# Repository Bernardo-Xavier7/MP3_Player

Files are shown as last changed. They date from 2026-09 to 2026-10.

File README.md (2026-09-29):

# Description
Just a simple MP3 player project. Features a built-in microphone, FM module, Wifi and Bluetooth, internal flash and SD card support and two audio ports.

# To-Do
- [ ] Hardware
  - [x] Schematic
    - [x] MCU
    - [x] USB
    - [x] Power
    - [x] Audio
    - [x] Storage
    - [x] Buttons
    - [x] Display
    - [x] Wireless
    - [x] Revision
    - [x] BOM
    - [x] Footprint Assignment
  - [ ] PCB
    - [ ] Layout
    - [ ] Routing
    - [ ] Revision
  - [ ] Firmware
    - [ ] Menu
      - [ ] Buttons
      - [ ] Display
    - [ ] USB Handling
    - [ ] Power Measuring and Display
    - [ ] Play Audio
    - [ ] Record
    - [ ] SD Card File System and Mass Storage
    - [ ] Wireless Conectivity
    - [ ] Revision
  - [ ] Case
    - [ ] Model
    - [ ] Test
    - [ ] Revision
# Useful Links
| Link | Description |
| ---- | ---- |
| https://snapeda.com | Symbols/Footprints/3DModels |
| https://octopart.com | Multi-seller component browser |
| https://buydisplay.com | Display shop |
| https://panelook.com | Display shop |
| [https://dev.st.com](https://dev.st.com/stm32cube-docs/stm32cube-getting-started/1.1.1/en/markup/Ecosystem_Select/Ecosystem_Select_MCU_Board.html) | STM32 development guide |

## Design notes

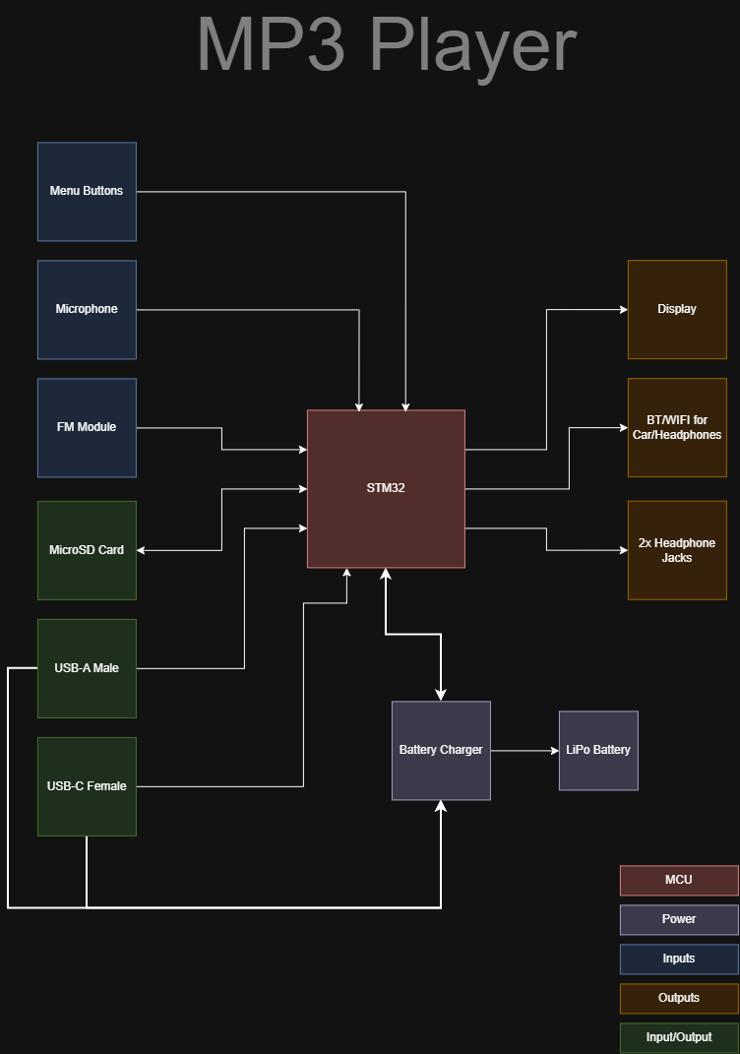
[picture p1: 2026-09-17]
PCB/MP3_Player/Drawings/MP3 Player.drawio.png

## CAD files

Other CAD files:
Case/MP3_Player.FCStd

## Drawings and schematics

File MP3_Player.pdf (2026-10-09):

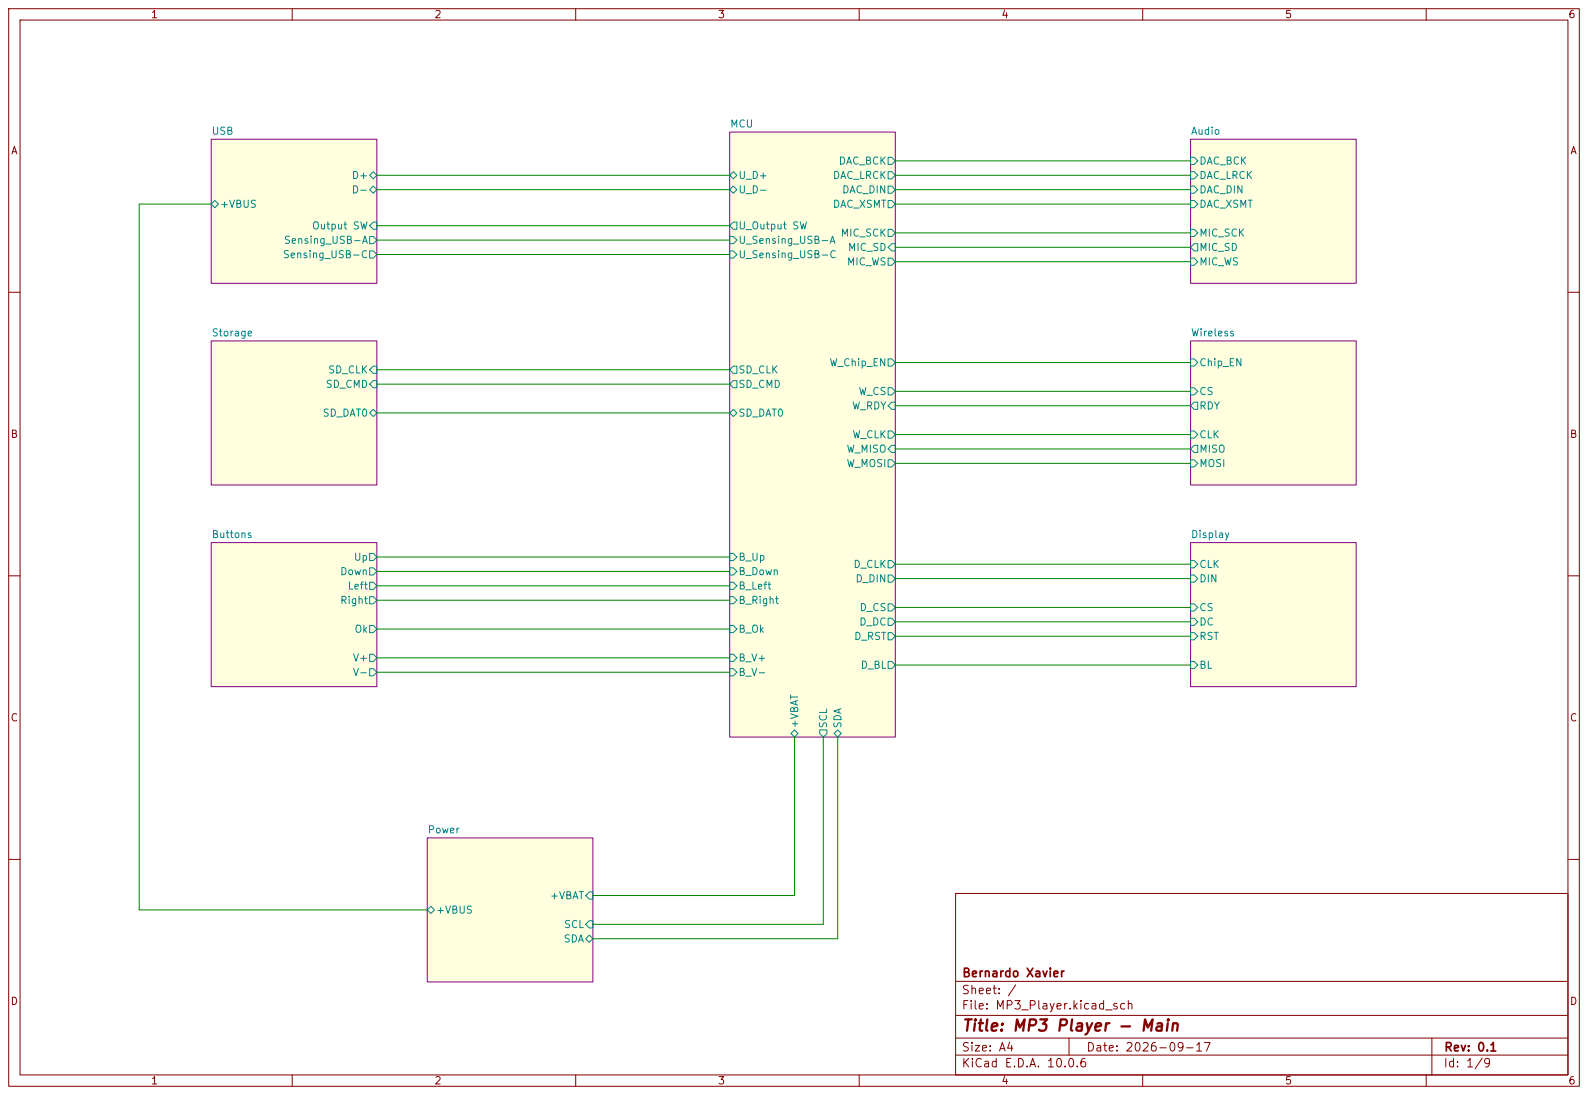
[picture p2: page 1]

Size: A4 | Rev: 0.1
KiCad E.D.A. 10.0.6 | Id: 1/9

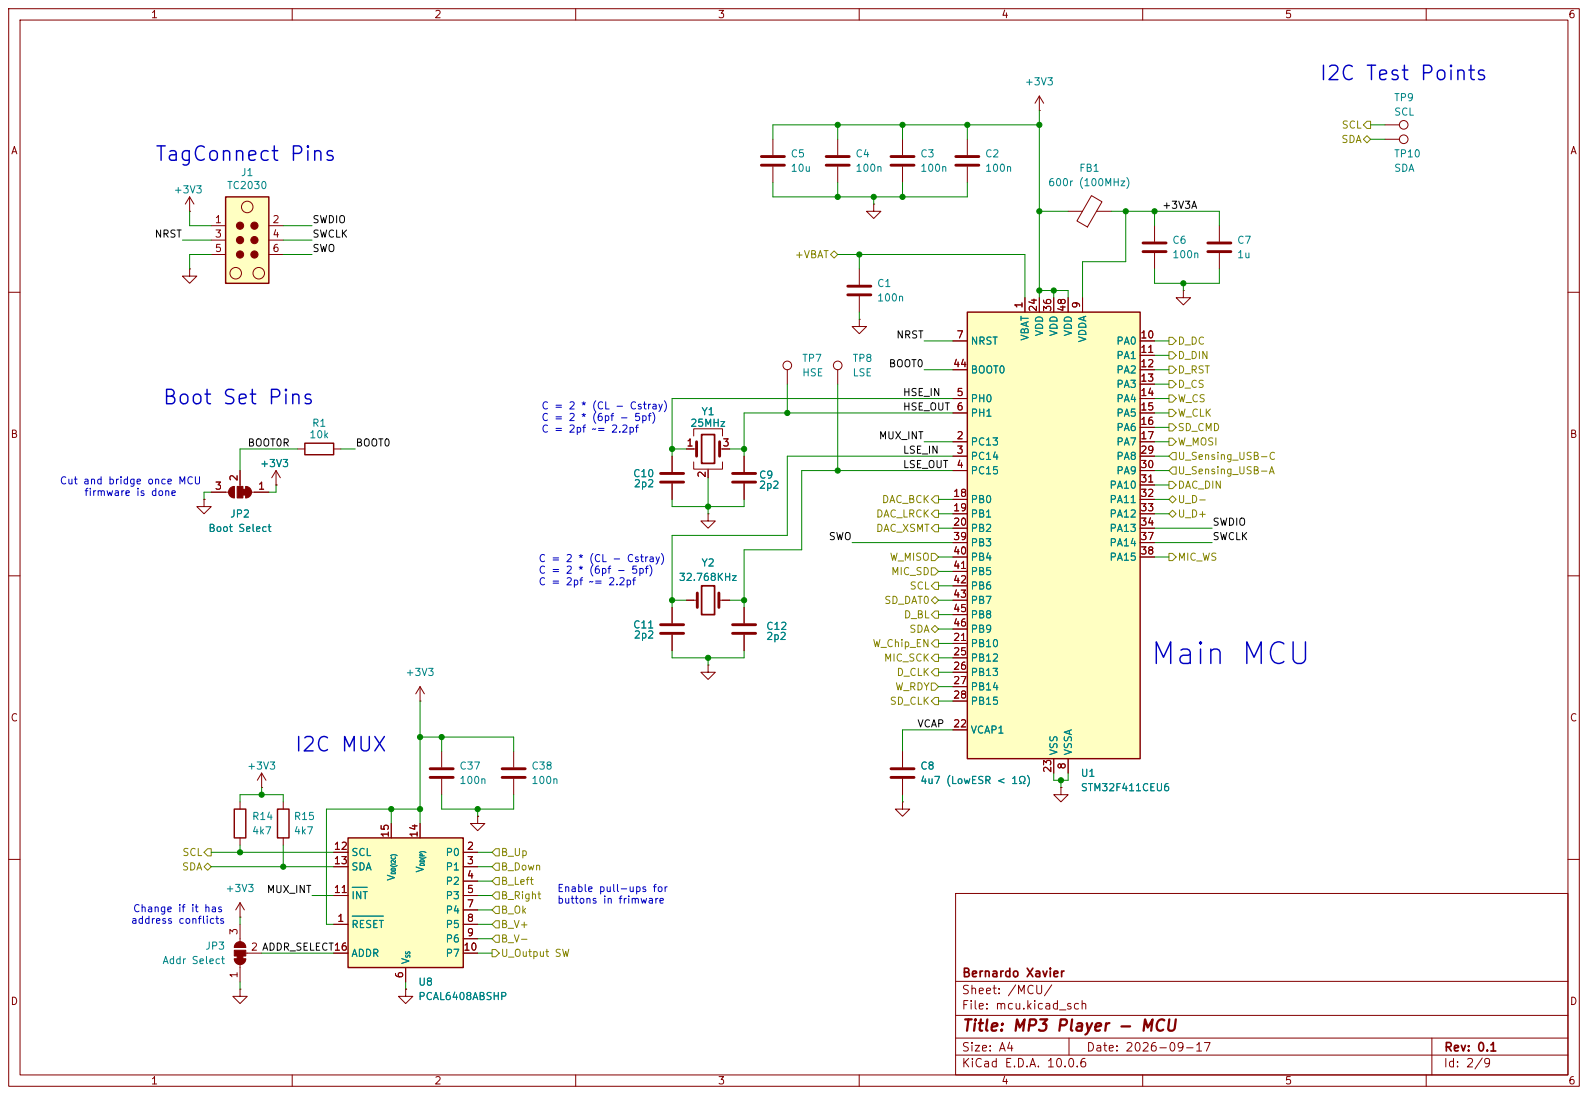
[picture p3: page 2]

C = 2 * (CL - Cstray) C = 2 * (6pf - 5pf) C = 2pf ~= 2.2pf C = 2 * (CL - Cstray) C = 2 * (6pf - 5pf) C = 2pf ~= 2.2pf Enable pull-ups for buttons in frimware TagConnect Pins

Cut and bridge once MCU

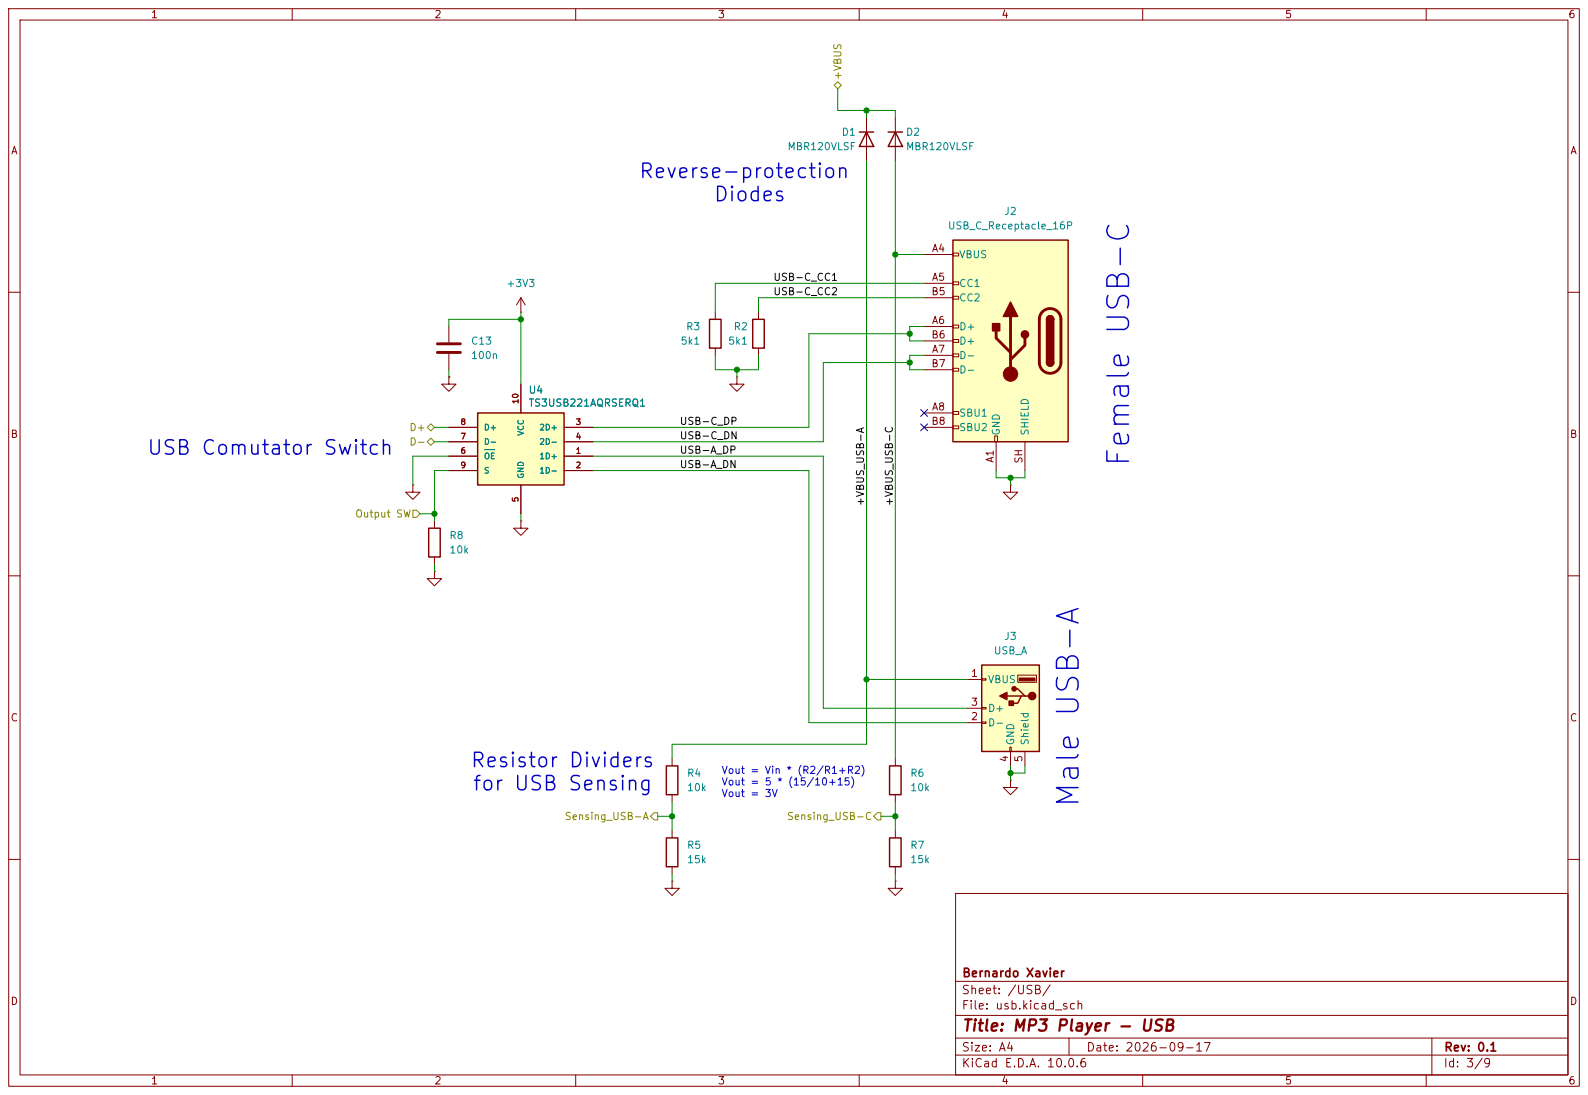
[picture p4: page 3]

SBU1 A8 CC2 B5 D+ B6 D- B7 SBU2 B8

SHIELD SH

Vout = Vin * (R2/R1+R2) Vout = 5 * (15/10+15) Vout = 3V USB Comutator Switch

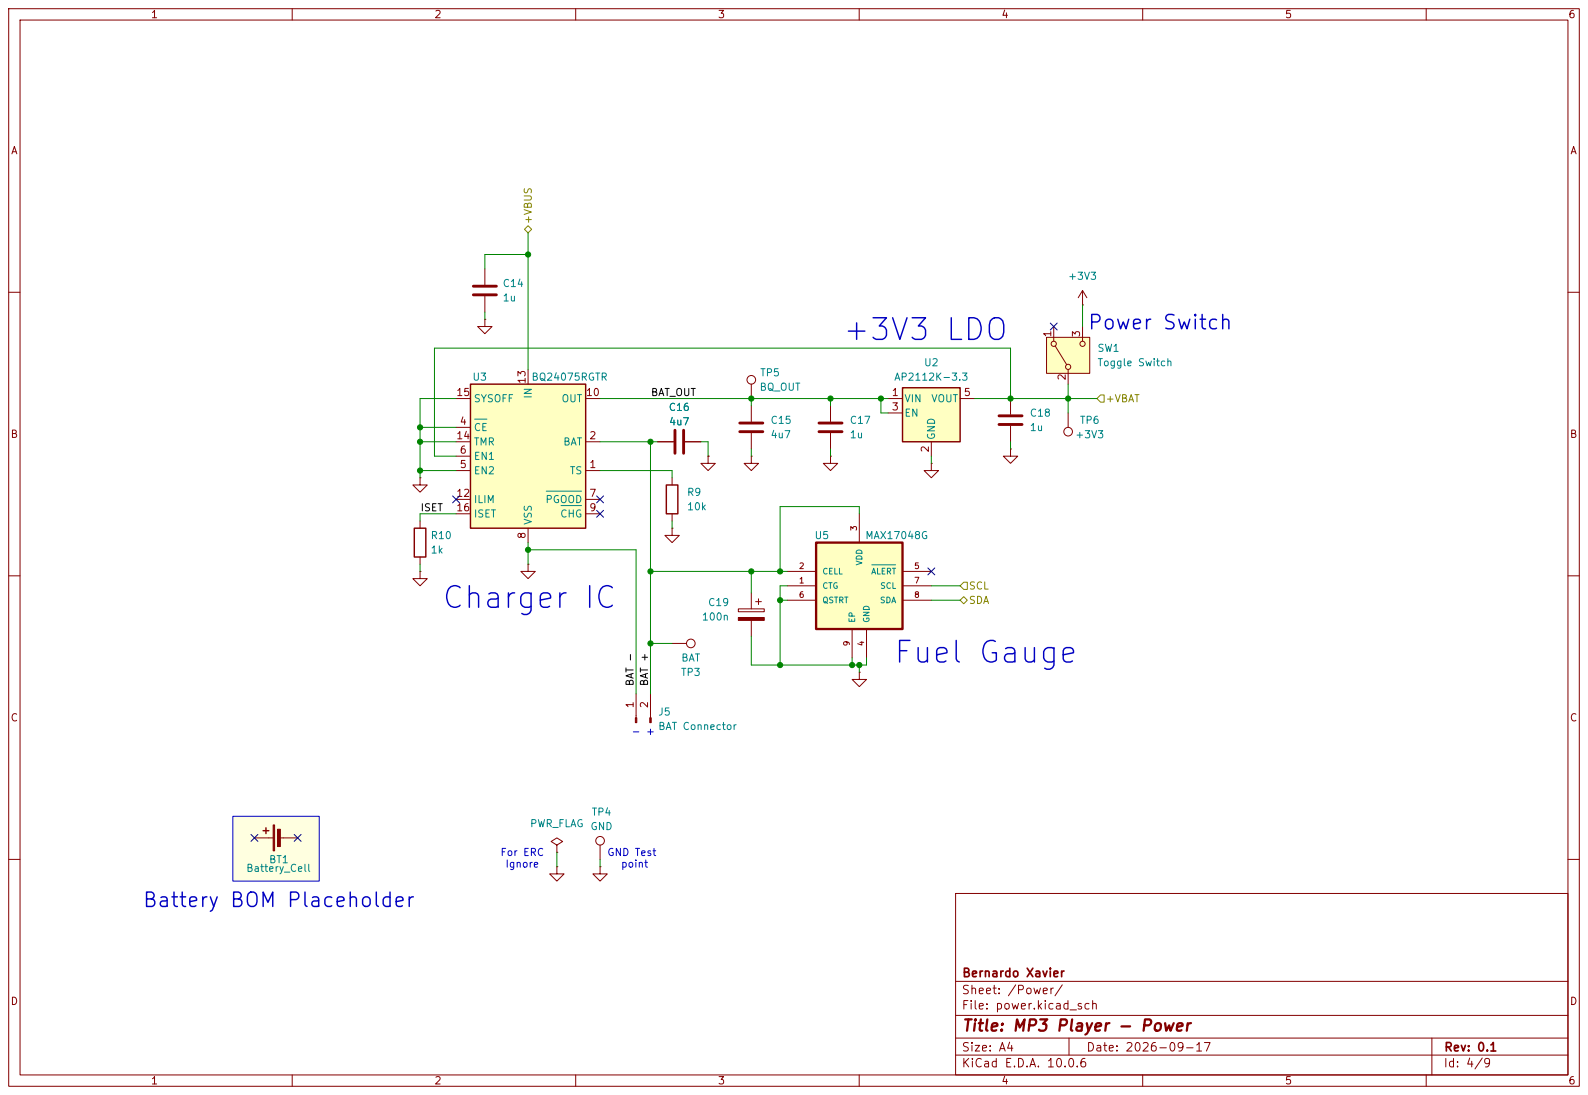
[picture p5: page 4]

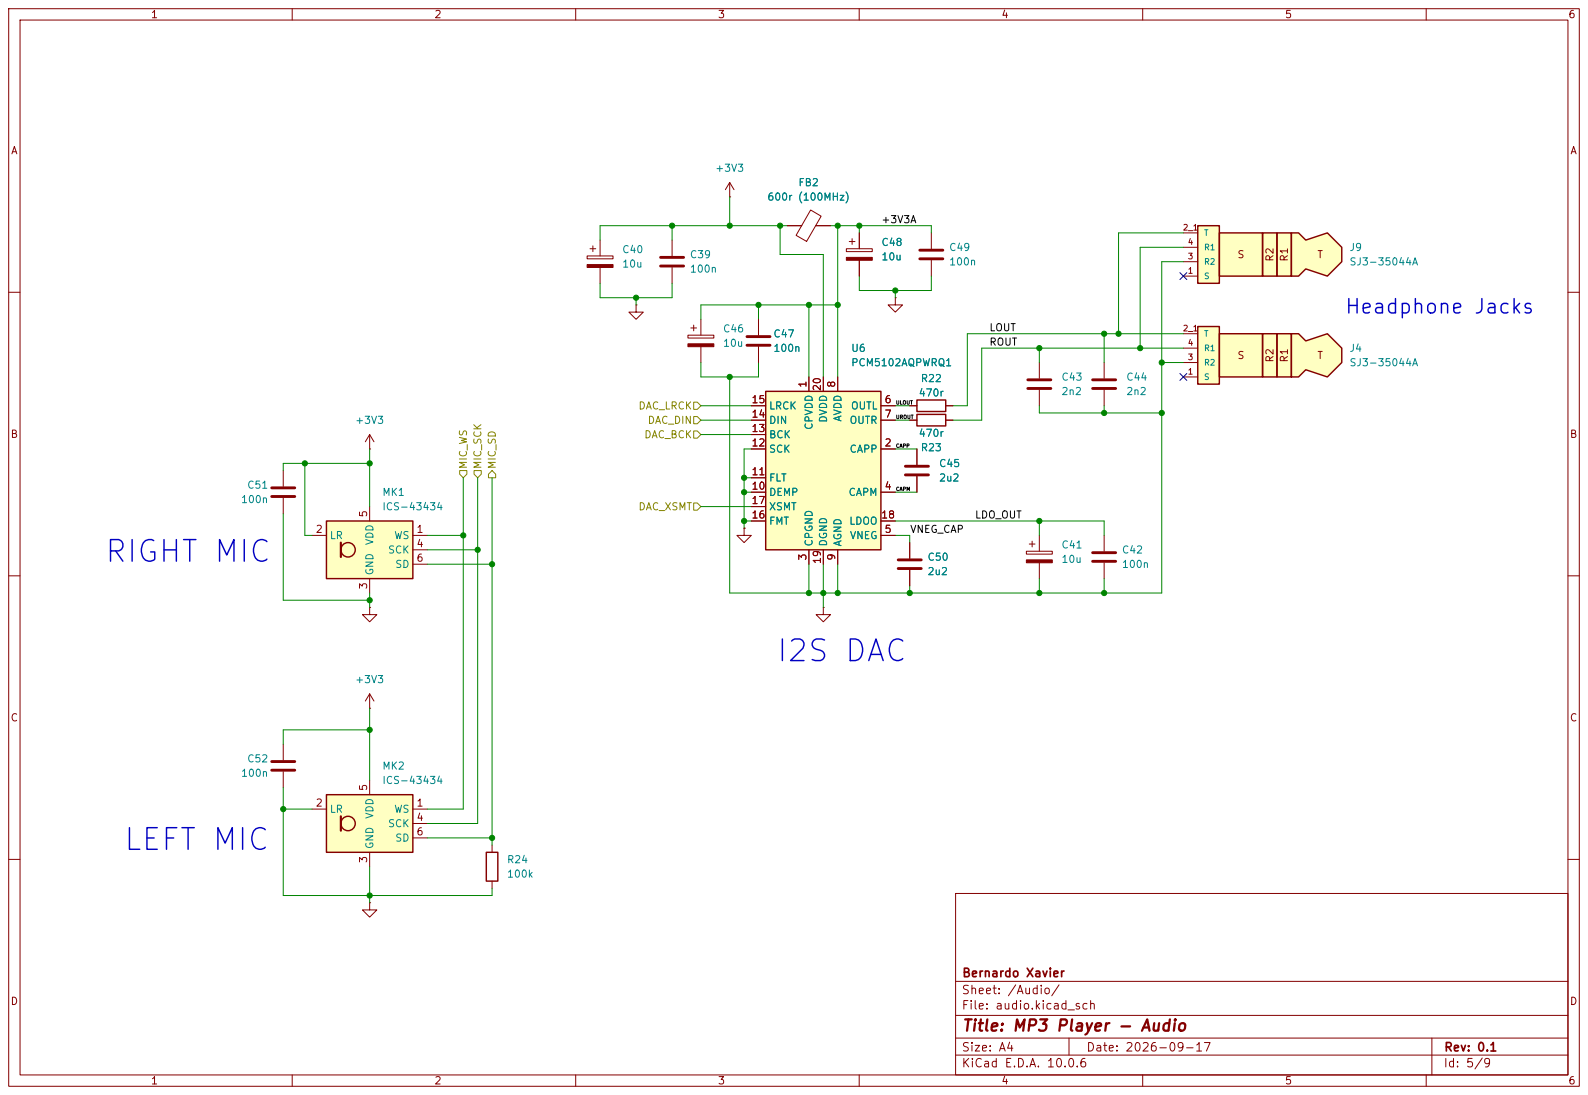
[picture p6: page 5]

SCK 12 BCK 13 DIN 14 LRCK 15

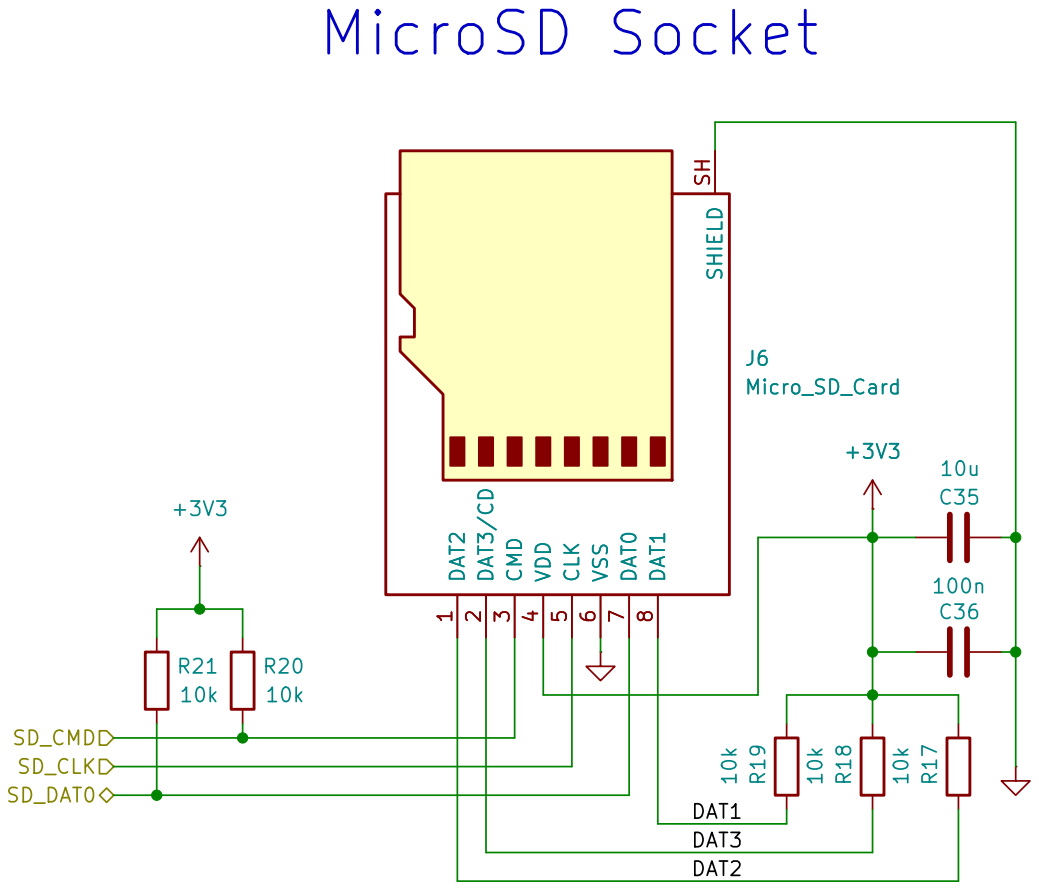
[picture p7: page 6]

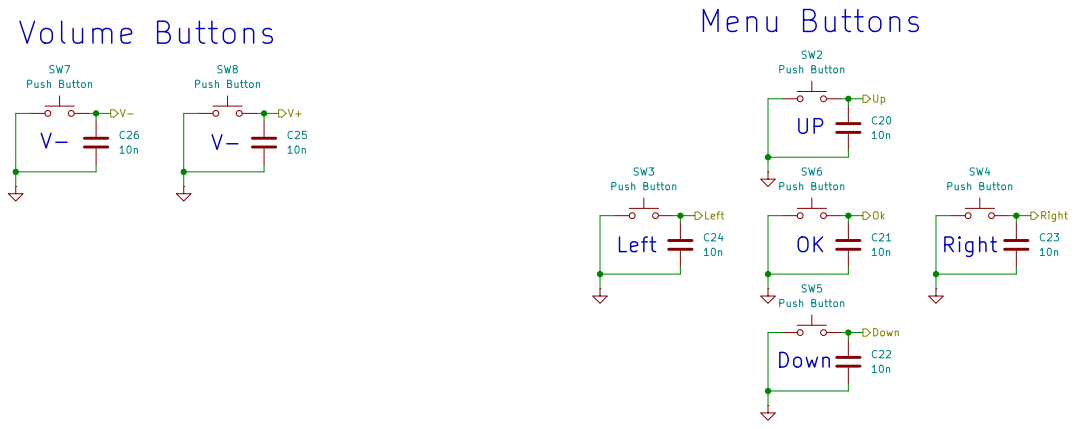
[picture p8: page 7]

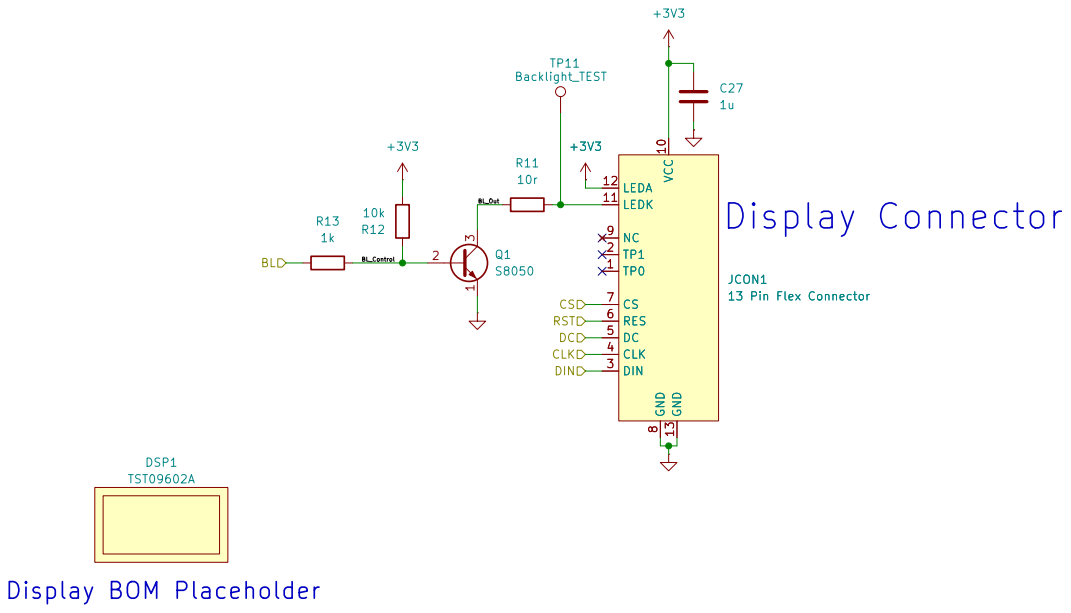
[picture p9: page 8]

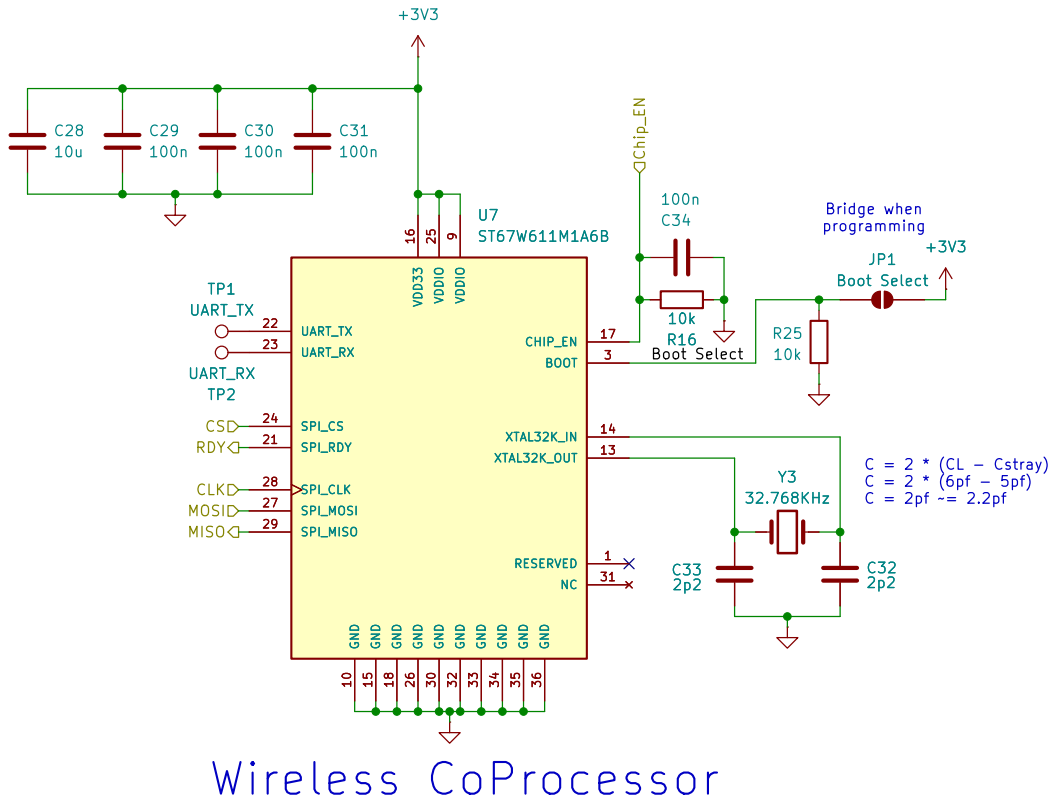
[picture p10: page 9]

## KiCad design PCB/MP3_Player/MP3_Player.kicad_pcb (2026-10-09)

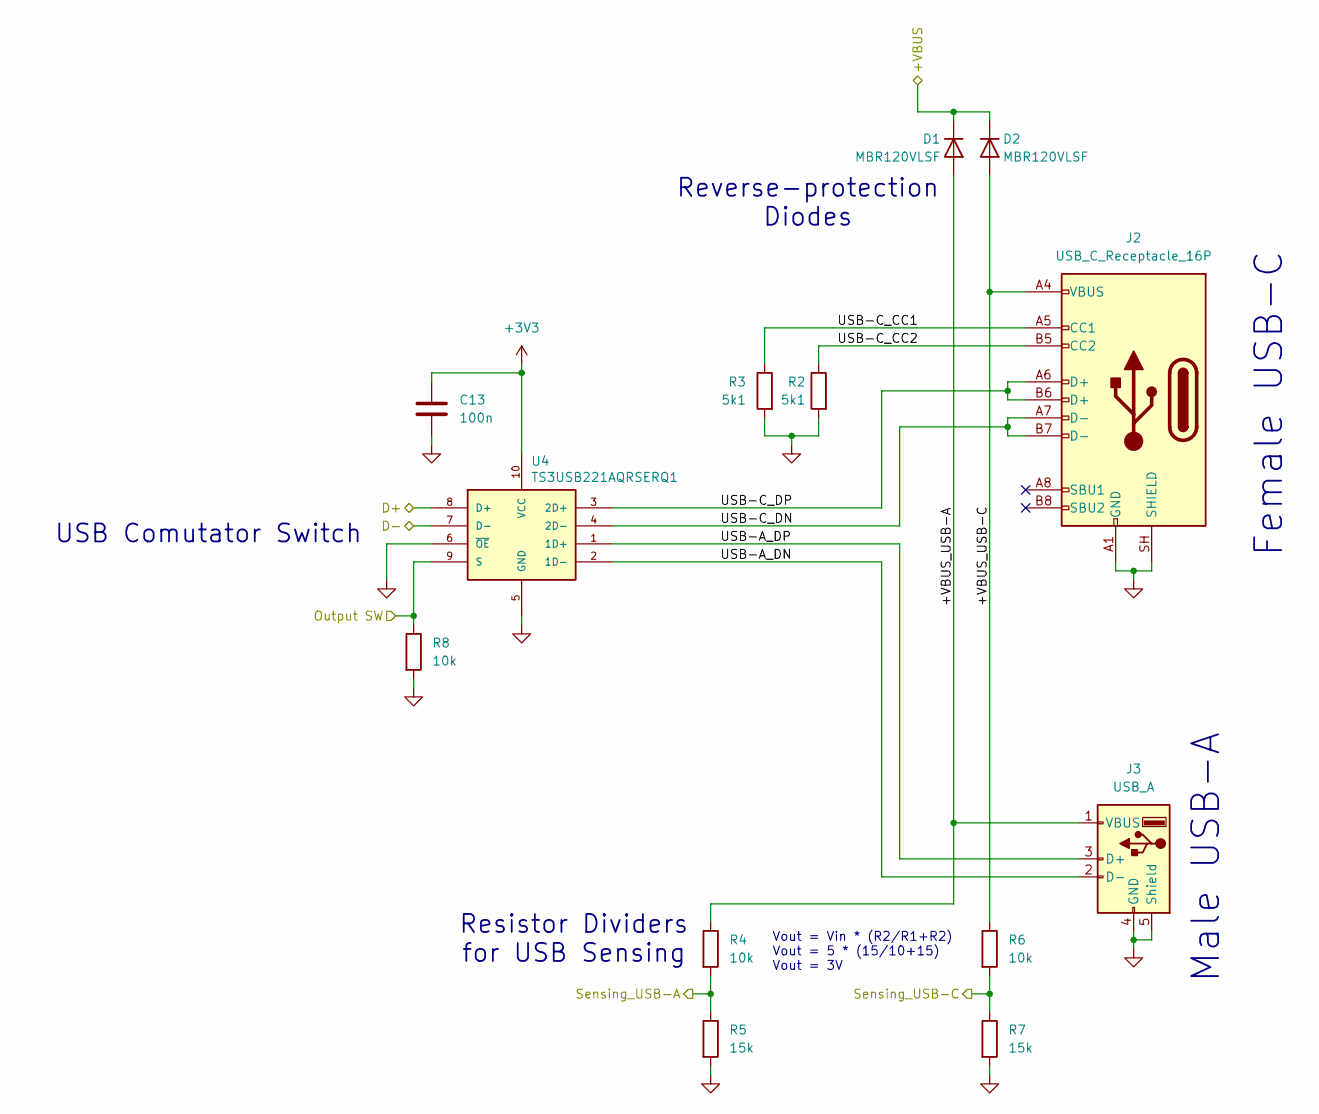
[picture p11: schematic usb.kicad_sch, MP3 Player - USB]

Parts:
C13: 100n; C_0402_1005Metric; Mfr. Part # CL05B104KP5NNNC
D1, D2: MBR120VLSF; D_SOD-123F; Mfr. Part # MBR120VLSFT3G
J2: USB_C_Receptacle_16P; USB_C_Receptacle_G-Switch_GT-USB-7010ASV; Mfr. Part # UJ20-C-H-C-4-SMT-TR
J3: USB_A; USB_A_CNCTech_1001-011-01101_Horizontal; Mfr. Part # 931
R2, R3: 5k1; R_0402_1005Metric; Mfr. Part # CRCW04025K10FKED
R4, R6, R8: 10k; R_0402_1005Metric; Mfr. Part # CRCW040210K0FKED
R5, R7: 15k; R_0402_1005Metric; Mfr. Part # CRCW040215K0FKED
U4: TS3USB221AQRSERQ1; MOUSER_PART_NUMBER 595-S3USB221AQRSERQ1

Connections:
+3V3: C13.1, U4.10 (VCC); also elsewhere on the board
/MCU/U_D+: U4.8 (D+); also elsewhere on the board
/MCU/U_D-: U4.7 (D-); also elsewhere on the board
/MCU/U_Output SW: R8.1, U4.9 (S); also elsewhere on the board
/MCU/U_Sensing_USB-A: R4.2, R5.1; also elsewhere on the board
/MCU/U_Sensing_USB-C: R6.2, R7.1; also elsewhere on the board
/Power/+VBUS: D1.1 (K), D2.1 (K); also elsewhere on the board
/USB/+VBUS_USB-A: D1.2 (A), J3.1 (VBUS), R4.1
/USB/+VBUS_USB-C: D2.2 (A), J2.A4 (VBUS), J2.A9 (VBUS), J2.B4 (VBUS), J2.B9 (VBUS), R6.1
/USB/USB-A_DN: J3.2 (D-), U4.2 (1D-)
/USB/USB-A_DP: J3.3 (D+), U4.1 (1D+)
/USB/USB-C_CC1: J2.A5 (CC1), R3.1
/USB/USB-C_CC2: J2.B5 (CC2), R2.1
/USB/USB-C_DN: J2.A7 (D-), J2.B7 (D-), U4.4 (2D-)
/USB/USB-C_DP: J2.A6 (D+), J2.B6 (D+), U4.3 (2D+)
GND: C13.2, J2.A1 (GND), J2.A12 (GND), J2.B1 (GND), J2.B12 (GND), J2.SH (SHIELD), J3.4 (GND), J3.5 (Shield), R2.2, R3.2, R5.2, R7.2, R8.2, U4.5 (GND), U4.6 (~OE); also elsewhere on the board

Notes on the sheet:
Vout = Vin * (R2/R1+R2) Vout = 5 * (15/10+15) Vout = 3V
Reverse-protection Diodes
USB Comutator Switch
Male USB-A
Resistor Dividers for USB Sensing
Female USB-C

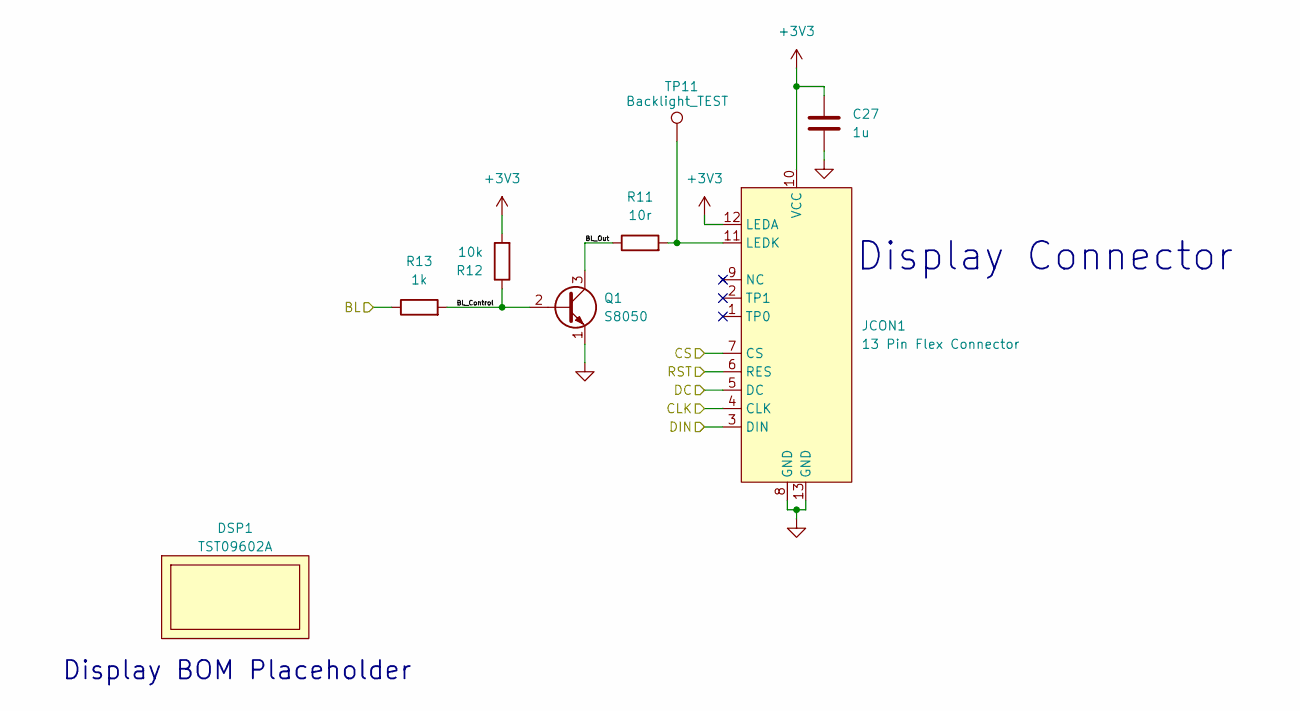
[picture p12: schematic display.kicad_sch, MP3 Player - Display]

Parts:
C27: 1u; C_0402_1005Metric; Mfr. Part # CL05A105MQ5NNND
DSP1: TST09602A; N/A; Mfr. Part # TST09602A
JCON1: 13 Pin Flex Connector; HRS_TF29-13S-0.4SH_800_; Mfr. Part # TF29-13S-0.4SH(800)
Q1: S8050; TSOT-23; Mfr. Part # S8050
R11: 10r; R_0603_1608Metric; Mfr. Part # CRCW060310R0FKEA
R12: 10k; R_0402_1005Metric; Mfr. Part # CRCW040210K0FKED
R13: 1k; R_0402_1005Metric; Mfr. Part # CRCW04021K00FKED
TP11: Backlight_TEST; TestPoint_Pad_D1.0mm

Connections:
+3V3: C27.1, JCON1.10 (VCC), JCON1.12 (LEDA), R12.2; also elsewhere on the board
/Display/BL: R13.1; also elsewhere on the board
/Display/BL_Control: Q1.2 (B), R12.1, R13.2
/Display/BL_Out: Q1.3 (C), R11.1
/Display/CLK: JCON1.4 (CLK); also elsewhere on the board
/Display/CS: JCON1.7 (CS); also elsewhere on the board
/Display/DC: JCON1.5 (DC); also elsewhere on the board
/Display/DIN: JCON1.3 (DIN); also elsewhere on the board
/Display/RST: JCON1.6 (RES); also elsewhere on the board
GND: C27.2, JCON1.8 (GND), JCON1.13 (GND), Q1.1 (E); also elsewhere on the board
unnamed: JCON1.11 (LEDK), R11.2, TP11.1 (1_1)

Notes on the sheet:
Display BOM Placeholder
Display Connector

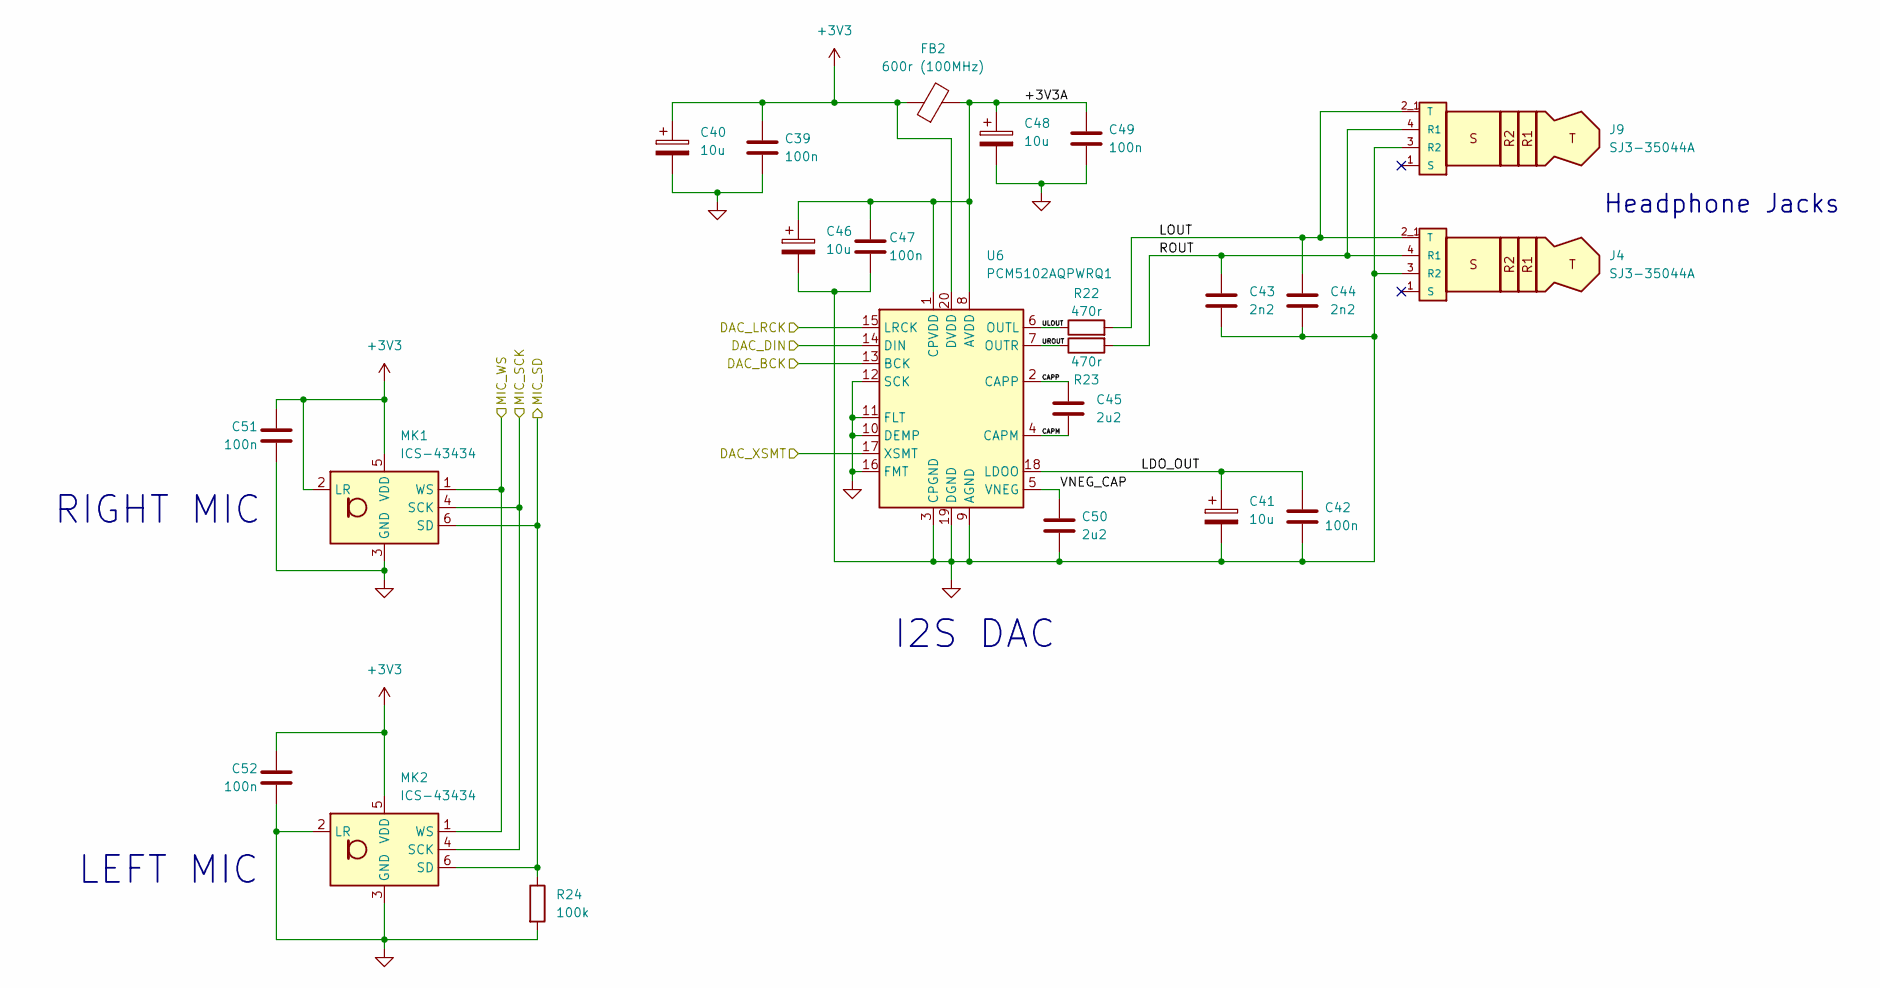
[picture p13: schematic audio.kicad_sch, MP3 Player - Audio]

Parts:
C39, C42, C47, C49, C51, C52: 100n; C_0402_1005Metric; Mfr. Part # CL05B104KP5NNNC
C40, C41, C46, C48: 10u; CP_EIA-2012-15_AVX-P; Mfr. Part # T529P106M010AAE200
C43, C44: 2n2; C_0402_1005Metric; Mfr. Part # CL05B222JB5NNNC
C45, C50: 2u2; C_0402_1005Metric; Mfr. Part # CL05A225MQ5NNND
FB2: 600r (100MHz); C_0402_1005Metric; Mfr. Part # BLM15AG601SN1D
J4, J9: SJ3-35044A; SAMESKY_SJ3-35044A; PARTREV 1.0
MK1, MK2: ICS-43434; InvenSense_ICS-43434-6_3.5x2.65mm; Mfr. Part # ICS-43434
R22, R23: 470r; R_0603_1608Metric; Mfr. Part # CRCW0603470RFKEA
R24: 100k; R_0402_1005Metric; Mfr. Part # CRCW0402100KFKED
U6: PCM5102AQPWRQ1; TSSOP-20_4.4x6.5mm_P0.65mm; Mfr. Part # PCM5102AQPWRQ1

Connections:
+3V3: C39.1, C40.1, C51.1, C52.1, FB2.1, MK1.2 (LR), MK1.5 (VDD), MK2.5 (VDD), U6.20 (DVDD); also elsewhere on the board
/Audio/+3V3A: C46.1, C47.1, C48.1, C49.1, FB2.2, U6.1 (CPVDD), U6.8 (AVDD)
/Audio/CAPM: C45.2, U6.4 (CAPM)
/Audio/CAPP: C45.1, U6.2 (CAPP)
/Audio/DAC_BCK: U6.13 (BCK); also elsewhere on the board
/Audio/DAC_DIN: U6.14 (DIN); also elsewhere on the board
/Audio/DAC_LRCK: U6.15 (LRCK); also elsewhere on the board
/Audio/DAC_XSMT: U6.17 (XSMT); also elsewhere on the board
/Audio/LDO_OUT: C41.1, C42.1, U6.18 (LDOO)
/Audio/LOUT: C44.1, J4.2_1 (T), J4.2_2, J9.2_1 (T), J9.2_2, R22.2
/Audio/MIC_SCK: MK1.4 (SCK), MK2.4 (SCK); also elsewhere on the board
/Audio/MIC_SD: MK1.6 (SD), MK2.6 (SD), R24.1; also elsewhere on the board
/Audio/MIC_WS: MK1.1 (WS), MK2.1 (WS); also elsewhere on the board
/Audio/ROUT: C43.1, J4.4 (R1), J9.4 (R1), R23.2
/Audio/ULOUT: R22.1, U6.6 (OUTL)
/Audio/UROUT: R23.1, U6.7 (OUTR)
/Audio/VNEG_CAP: C50.1, U6.5 (VNEG)
GND: C39.2, C40.2, C41.2, C42.2, C43.2, C44.2, C46.2, C47.2, C48.2, C49.2, C50.2, C51.2, C52.2, J4.3 (R2), J9.3 (R2), MK1.3 (GND), MK2.2 (LR), MK2.3 (GND), R24.2, U6.3 (CPGND), U6.9 (AGND), U6.10 (DEMP), U6.11 (FLT), U6.12 (SCK), U6.16 (FMT), U6.19 (DGND); also elsewhere on the board

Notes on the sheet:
Headphone Jacks
LEFT MIC
I2S DAC
RIGHT MIC

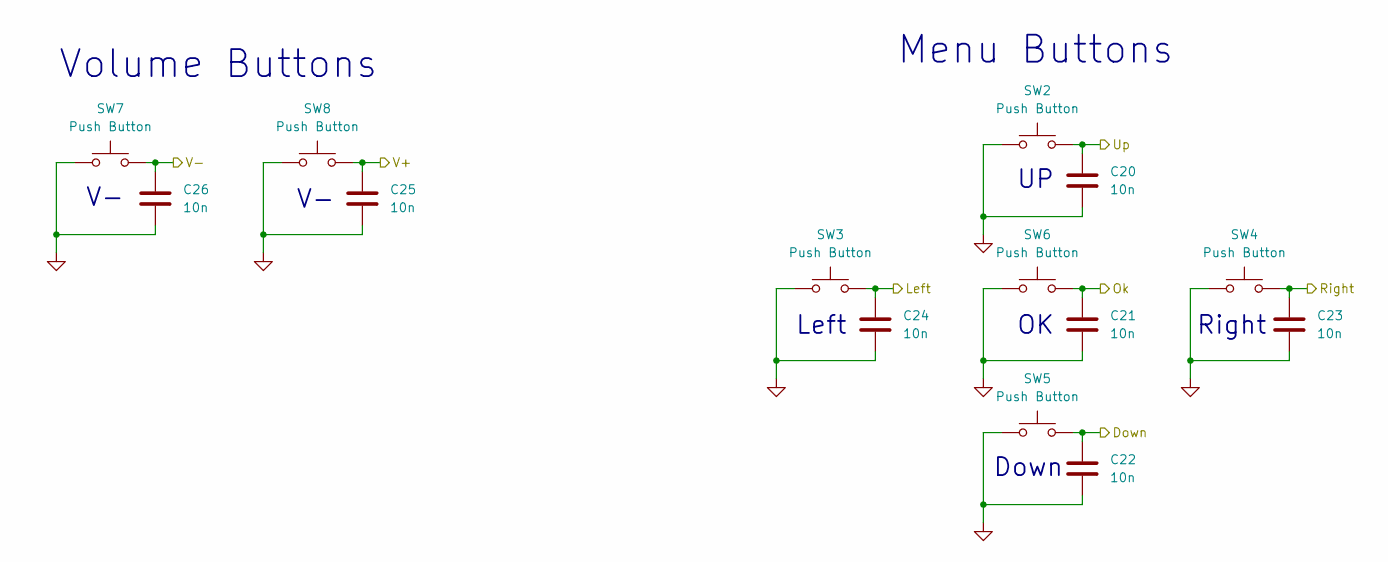
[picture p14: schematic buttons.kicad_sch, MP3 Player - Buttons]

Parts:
C20, C21, C22, C23, C24, C25, C26: 10n; C_0402_1005Metric; Mfr. Part # CL05B103KB5NNND
SW2, SW3, SW4, SW5, SW6, SW7, SW8: Push Button

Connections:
/Buttons/Down: C22.1, SW5.1; also elsewhere on the board
/Buttons/Left: C24.1, SW3.2; also elsewhere on the board
/Buttons/Ok: C21.1, SW6.2; also elsewhere on the board
/Buttons/Right: C23.1, SW4.1; also elsewhere on the board
/Buttons/Up: C20.1, SW2.2; also elsewhere on the board
/Buttons/V+: C25.1, SW8.1; also elsewhere on the board
/Buttons/V-: C26.1, SW7.2; also elsewhere on the board
GND: C20.2, C21.2, C22.2, C23.2, C24.2, C25.2, C26.2, SW2.1, SW3.1, SW4.2, SW5.2, SW6.1, SW7.1, SW8.2; also elsewhere on the board

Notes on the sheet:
Right
Down
Menu Buttons
Left
Volume Buttons

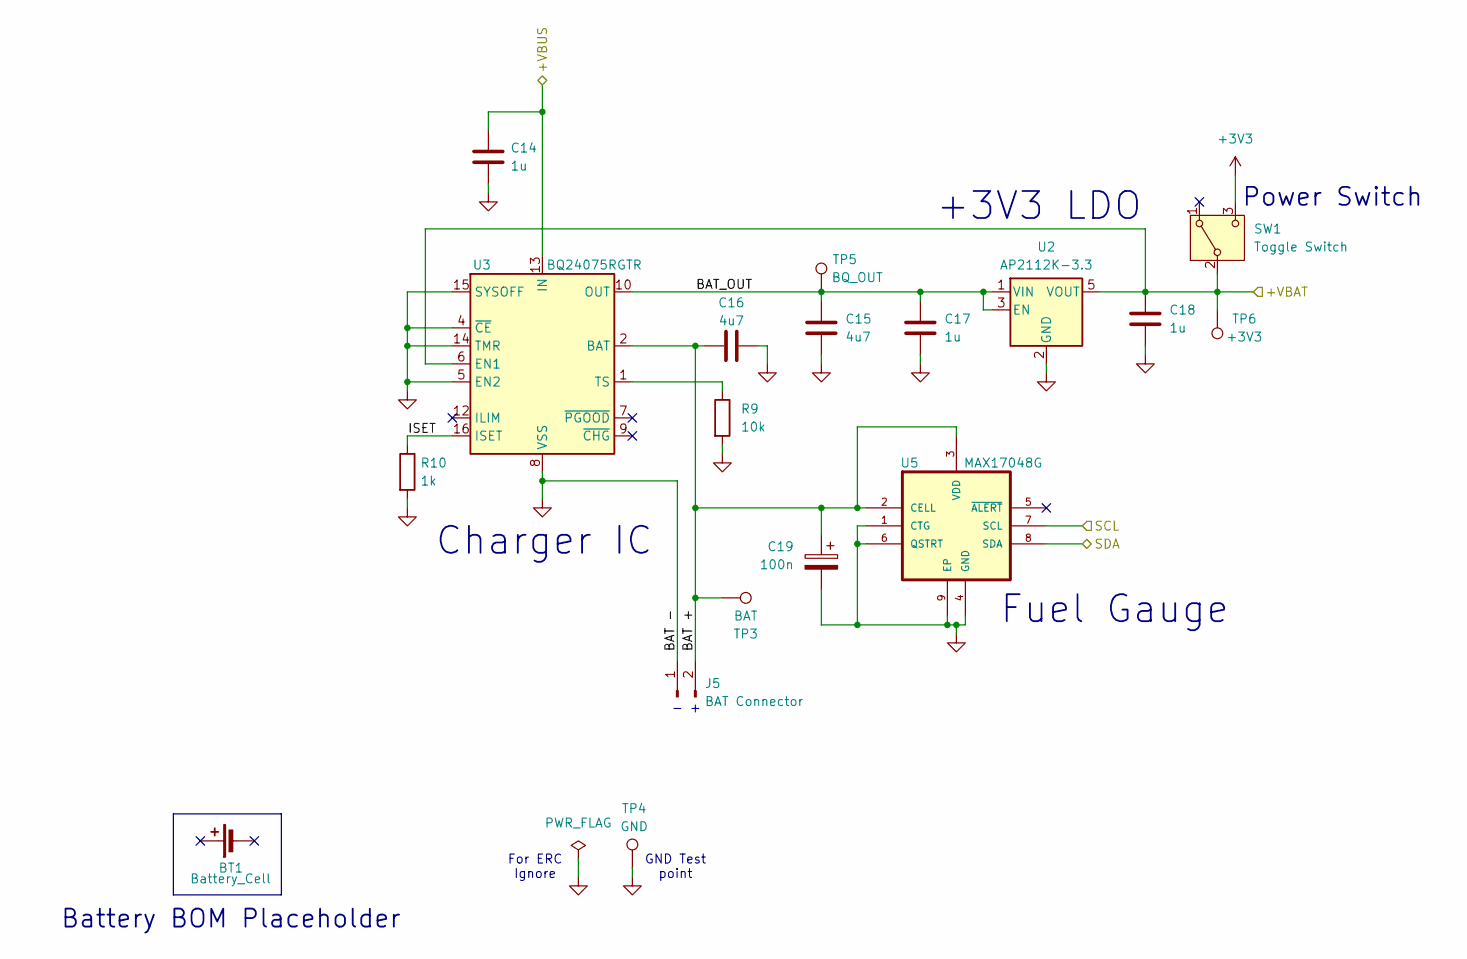
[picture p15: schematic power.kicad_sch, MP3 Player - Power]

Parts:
BT1: Battery_Cell; N/A
C14, C17, C18: 1u; C_0402_1005Metric; Mfr. Part # CL05A105MQ5NNND
C15, C16: 4u7; C_0603_1608Metric; Mfr. Part # CL10A475KQ8NNNL
C19: 100n; C_0402_1005Metric; Mfr. Part # CL05B104KP5NNNC
J5: BAT Connector; JST_PH_S2B-PH-SM4-TB_1x02-1MP_P2.00mm_Horizontal; Mfr. Part # S2B-PH-SM4-TB
R9: 10k; R_0402_1005Metric; Mfr. Part # CRCW040210K0FKED
R10: 1k; R_0402_1005Metric; Mfr. Part # CRCW04021K00FKED
SW1: Toggle Switch; SW_SPDT_CK_JS102011SAQN; Mfr. Part # SWS010-020R12SSA
TP3: BAT; TestPoint_Pad_D1.0mm
TP4: GND; TestPoint_Pad_D1.0mm
TP5: BQ_OUT; TestPoint_Pad_D1.0mm
TP6: +3V3; TestPoint_Pad_D1.0mm
U2: AP2112K-3.3; SOT-23-5; Mfr. Part # AP2112K-3.3TRG1
U3: BQ24075RGTR; VQFN-16-1EP_3x3mm_P0.5mm_EP1.6x1.6mm; Mfr. Part # BQ24075RGTR
U5: MAX17048G; SON50P200X200X80-9N; Mfr. Part # MAX17048G+T10

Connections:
+3V3: SW1.3 (C); also elsewhere on the board
/MCU/+VBAT: C18.1, SW1.2 (B), TP6.1 (1_1), U2.5 (VOUT), U3.6 (EN1); also elsewhere on the board
/MCU/SCL: U5.7 (SCL); also elsewhere on the board
/MCU/SDA: U5.8 (SDA); also elsewhere on the board
/Power/+VBUS: C14.1, U3.13 (IN); also elsewhere on the board
/Power/BAT +: C16.1, C19.1, J5.2, TP3.1 (1_1), U3.2 (BAT), U3.3 (BAT), U5.2 (CELL), U5.3 (VDD)
/Power/BAT_OUT: C15.1, C17.1, TP5.1 (1_1), U2.1 (VIN), U2.3 (EN), U3.10 (OUT), U3.11 (OUT)
/Power/ISET: R10.1, U3.16 (ISET)
GND: C14.2, C15.2, C16.2, C17.2, C18.2, C19.2, J5.1, R9.2, R10.2, TP4.1 (1_1), U2.2 (GND), U3.4 (~CE), U3.5 (EN2), U3.8 (VSS), U3.14 (TMR), U3.15 (SYSOFF), U3.17 (VSS), U5.1 (CTG), U5.4 (GND), U5.6 (QSTRT), U5.9 (EP); also elsewhere on the board
unnamed: R9.1, U3.1 (TS)

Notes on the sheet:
Charger IC
Battery BOM Placeholder
+3V3 LDO
- +
For ERC Ignore
Fuel Gauge
GND Test point
Power Switch

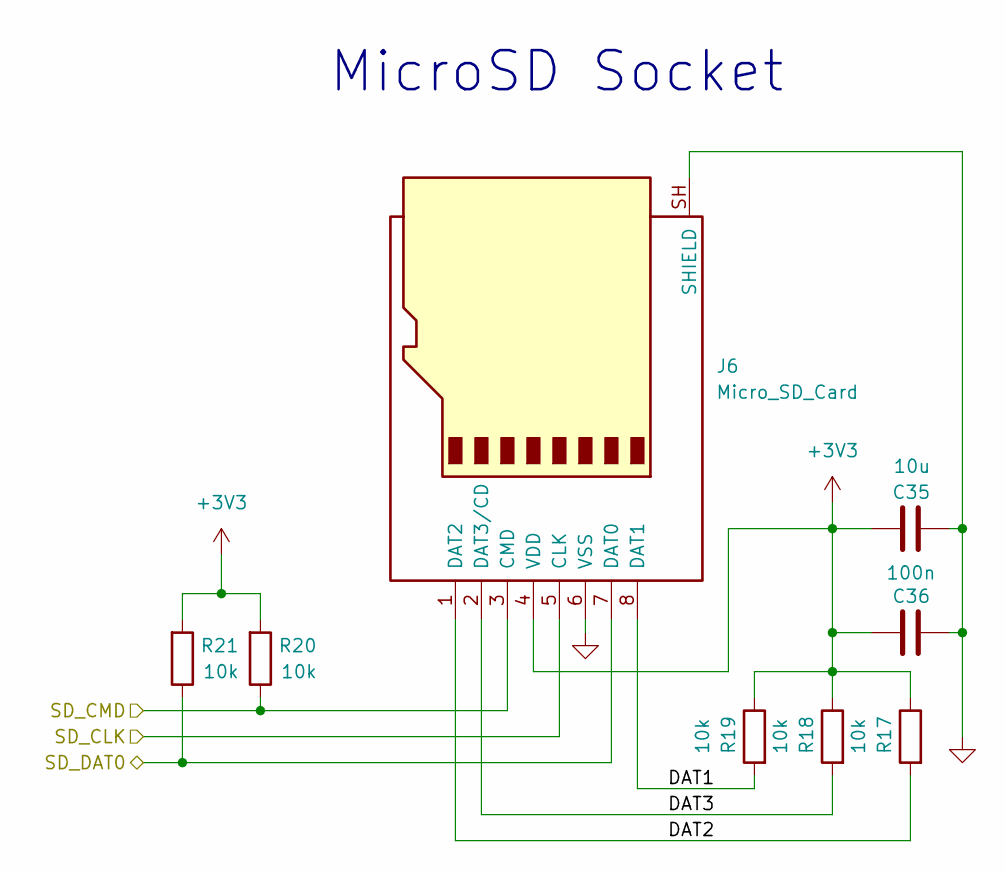
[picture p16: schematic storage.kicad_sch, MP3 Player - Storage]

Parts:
C35: 10u; C_0603_1608Metric; Mfr. Part # CL10A106KP8NNNC
C36: 100n; C_0402_1005Metric; Mfr. Part # CL05B104KP5NNNC
J6: Micro_SD_Card; CUI_MSD-1-A; Mfr. Part # MSD-1-A
R17, R18, R19, R20, R21: 10k; R_0402_1005Metric; Mfr. Part # CRCW040210K0FKED

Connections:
+3V3: C35.1, C36.1, J6.4 (VDD), R17.1, R18.1, R19.1, R20.2, R21.2; also elsewhere on the board
/MCU/SD_CLK: J6.5 (CLK); also elsewhere on the board
/MCU/SD_CMD: J6.3 (CMD), R20.1; also elsewhere on the board
/MCU/SD_DAT0: J6.7 (DAT0), R21.1; also elsewhere on the board
/Storage/DAT1: J6.8 (DAT1), R19.2
/Storage/DAT2: J6.1 (DAT2), R17.2
/Storage/DAT3: J6.2 (DAT3/CD), R18.2
GND: C35.2, C36.2, J6.6 (VSS), J6.SH (SHIELD); also elsewhere on the board

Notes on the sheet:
MicroSD Socket

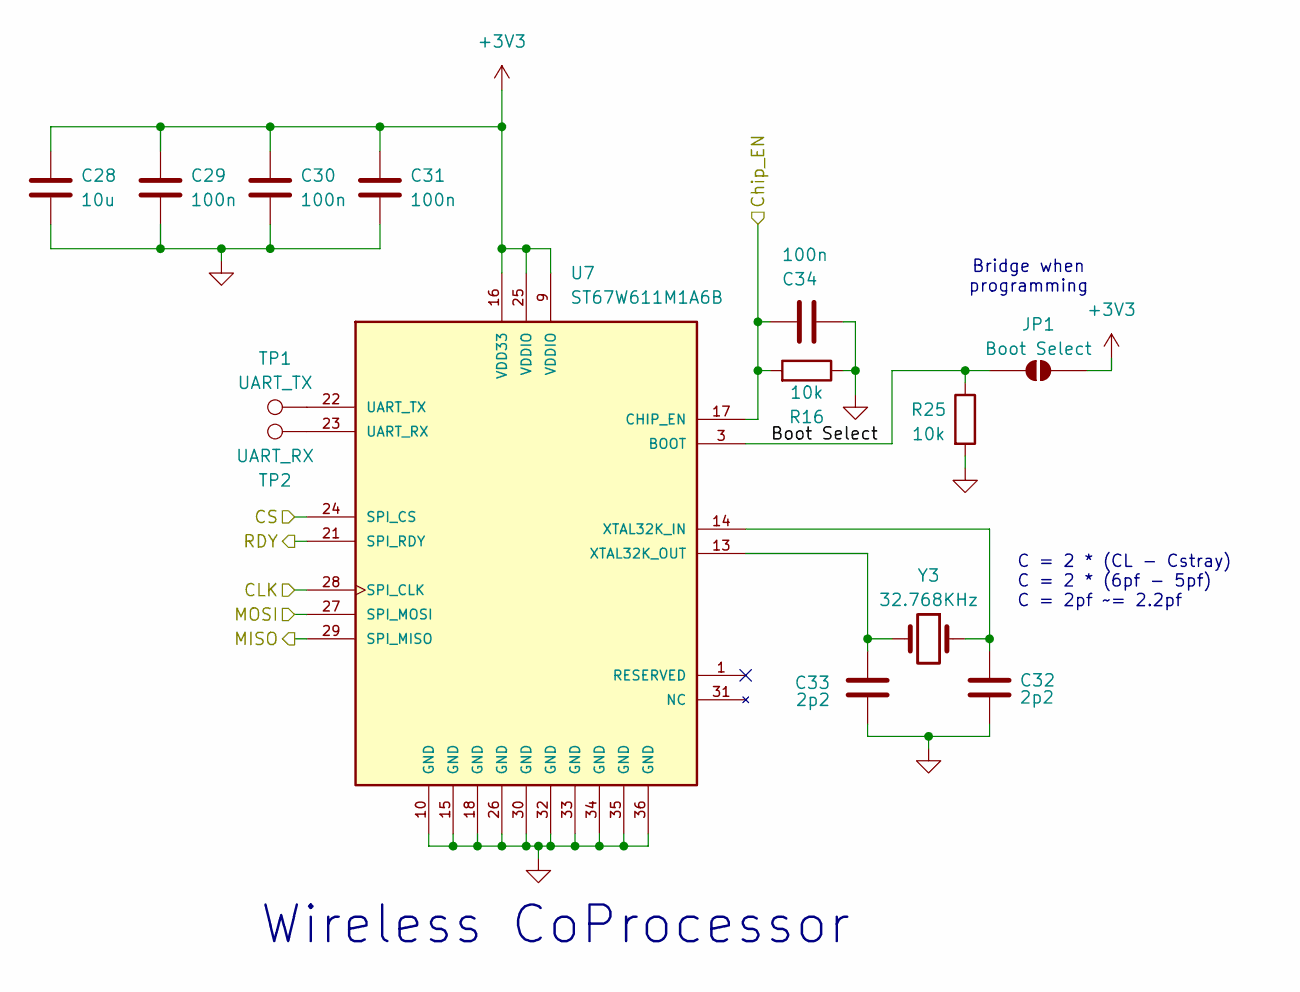
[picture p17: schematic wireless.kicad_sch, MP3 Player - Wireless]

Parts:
C28: 10u; C_0603_1608Metric; Mfr. Part # CL10A106KP8NNNC
C29, C30, C31, C34: 100n; C_0402_1005Metric; Mfr. Part # CL05B104KP5NNNC
C32, C33: 2p2; C_0402_1005Metric; Mfr. Part # CL05C2R2CB51PNC
JP1: Boot Select; SolderJumper-2_P1.3mm_Bridged2Bar_RoundedPad1.0x1.5mm
R16, R25: 10k; R_0402_1005Metric; Mfr. Part # CRCW040210K0FKED
TP1: UART_TX; TestPoint_Pad_D1.0mm
TP2: UART_RX; TestPoint_Pad_D1.0mm
U7: ST67W611M1A6B; MODULE_ST67W611M1A6BTR; PARTREV 4
Y3: 32.768KHz; Crystal_SMD_2012-2Pin_2.0x1.2mm; Mfr. Part # FC2012SN

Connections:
+3V3: C28.1, C29.1, C30.1, C31.1, JP1.2 (B), U7.9 (VDDIO), U7.16 (VDD33), U7.25 (VDDIO); also elsewhere on the board
/MCU/W_CLK: U7.28 (SPI_CLK); also elsewhere on the board
/MCU/W_CS: U7.24 (SPI_CS); also elsewhere on the board
/MCU/W_Chip_EN: C34.2, R16.2, U7.17 (CHIP_EN); also elsewhere on the board
/MCU/W_MISO: U7.29 (SPI_MISO); also elsewhere on the board
/MCU/W_MOSI: U7.27 (SPI_MOSI); also elsewhere on the board
/MCU/W_RDY: U7.21 (SPI_RDY); also elsewhere on the board
/Wireless/Boot Select: JP1.1 (A), R25.1, U7.3 (BOOT)
GND: C28.2, C29.2, C30.2, C31.2, C32.2, C33.2, C34.1, R16.1, R25.2, U7.10 (GND), U7.15 (GND), U7.18 (GND), U7.26 (GND), U7.30 (GND), U7.32 (GND), U7.33 (GND), U7.34 (GND), U7.35 (GND), U7.36 (GND); also elsewhere on the board
unnamed: TP2.1 (1_1), U7.23 (UART_RX)
unnamed: TP1.1 (1_1), U7.22 (UART_TX)
unnamed: C32.1, U7.14 (XTAL32K_IN), Y3.1
unnamed: C33.1, U7.13 (XTAL32K_OUT), Y3.2

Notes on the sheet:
Wireless CoProcessor
C = 2 * (CL - Cstray) C = 2 * (6pf - 5pf) C = 2pf ~= 2.2pf
Bridge when programming

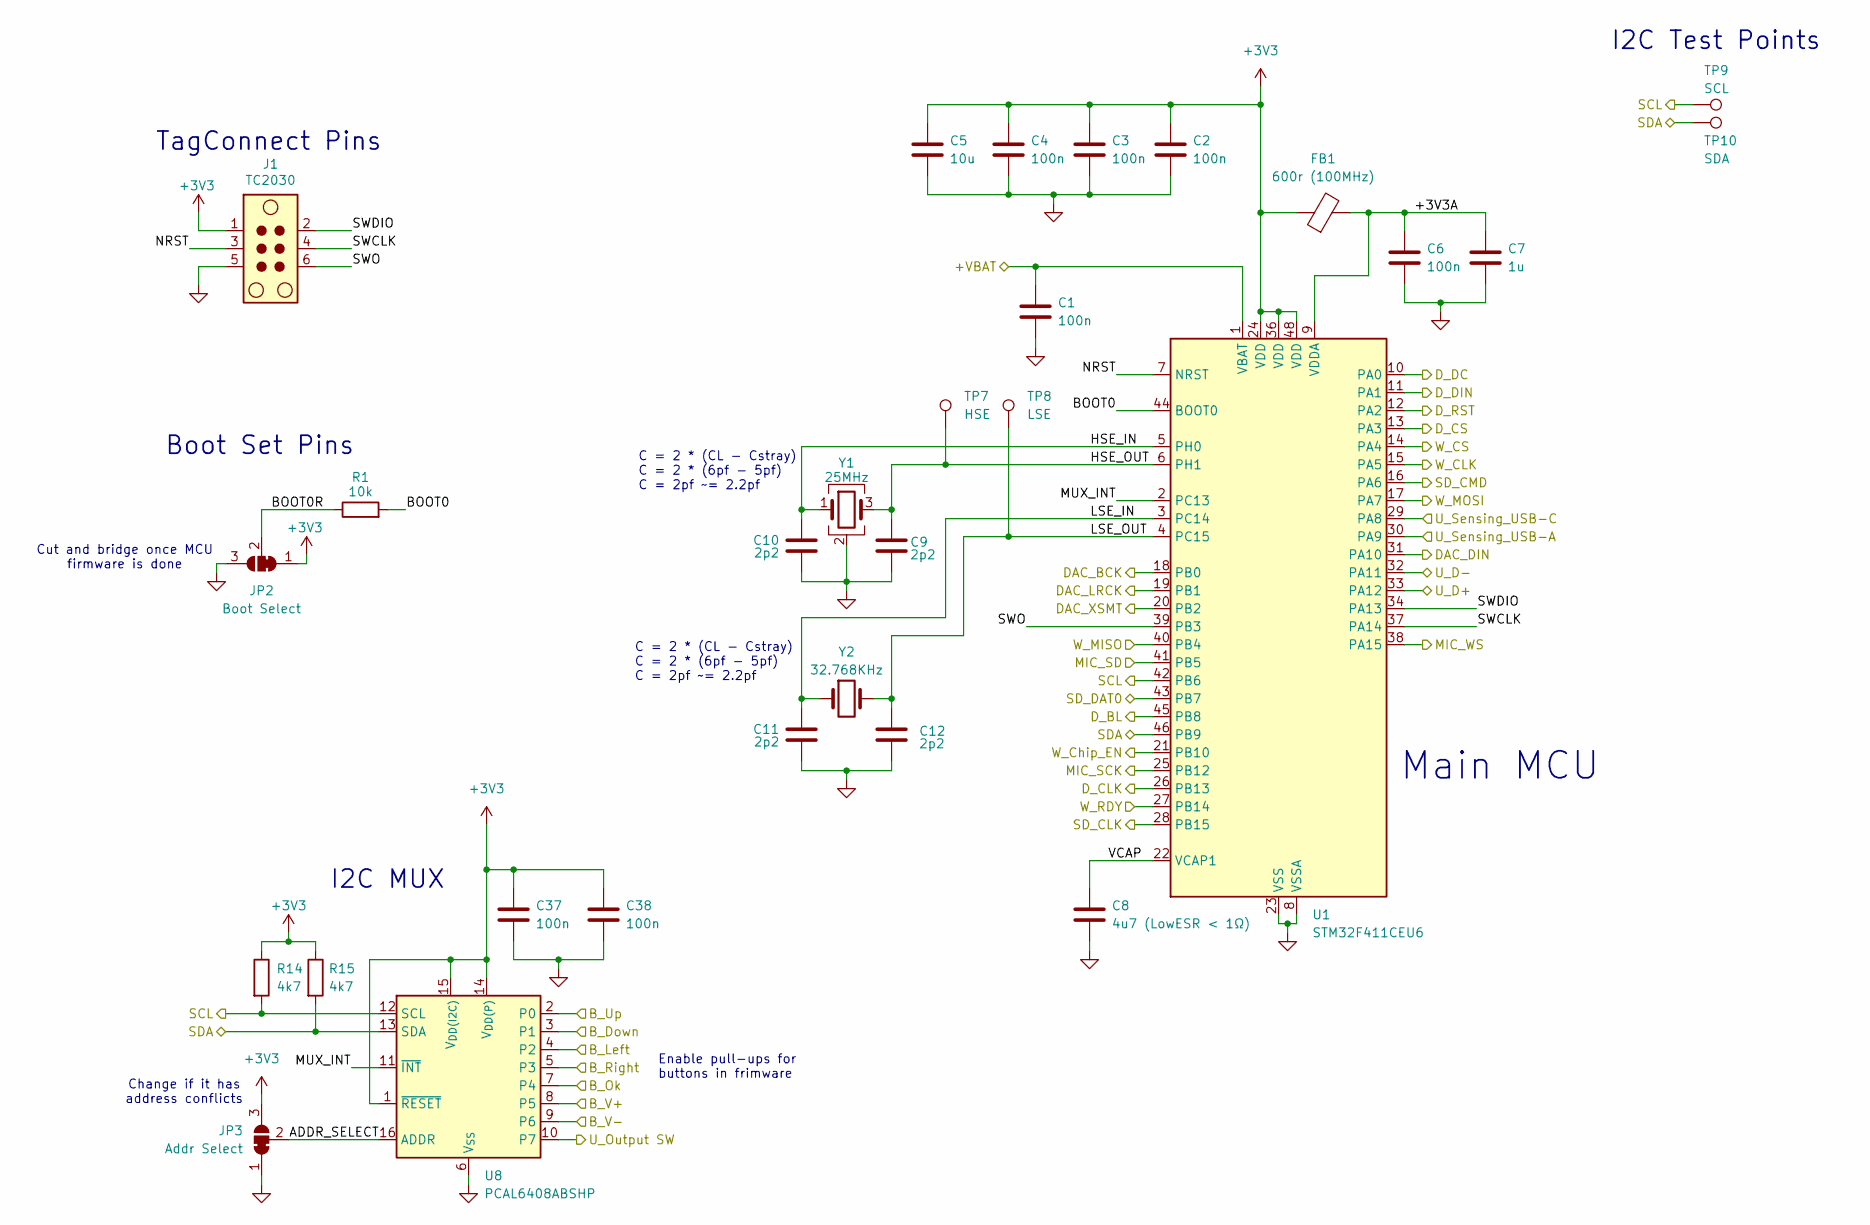
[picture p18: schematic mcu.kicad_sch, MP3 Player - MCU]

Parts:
C1, C2, C3, C4, C6, C37, C38: 100n; C_0402_1005Metric; Mfr. Part # CL05B104KP5NNNC
C5: 10u; C_0603_1608Metric; Mfr. Part # CL10A106KP8NNNC
C7: 1u; C_0402_1005Metric; Mfr. Part # CL05A105MQ5NNND
C8: 4u7 (LowESR < 1Ω); C_0603_1608Metric; Mfr. Part # CL10A475KA8NQNC
C9, C10, C11, C12: 2p2; C_0402_1005Metric; Mfr. Part # CL05C2R2CB51PNC
FB1: 600r (100MHz); C_0402_1005Metric; Mfr. Part # BLM15AG601SN1D
J1: TC2030; Tag-Connect_TC2030-IDC-NL_2x03_P1.27mm_Vertical
JP2: Boot Select; SolderJumper-3_P1.3mm_Bridged12_RoundedPad1.0x1.5mm
JP3: Addr Select; SolderJumper-3_P1.3mm_Bridged12_RoundedPad1.0x1.5mm
R1: 10k; R_0402_1005Metric; Mfr. Part # CRCW040210K0FKED
R14, R15: 4k7; R_0402_1005Metric; Mfr. Part # CRCW04024K70FKED
TP7: HSE; TestPoint_Pad_D1.0mm
TP8: LSE; TestPoint_Pad_D1.0mm
TP9: SCL; TestPoint_Pad_D1.0mm
TP10: SDA; TestPoint_Pad_D1.0mm
U1: STM32F411CEU6; QFN-48-1EP_7x7mm_P0.5mm_EP5.6x5.6mm; Mfr. Part # STM32F411CEU6
U8: PCAL6408ABSHP; VQFN-16-1EP_3x3mm_P0.5mm_EP1.6x1.6mm; Mfr. Part # PCAL6408ABSHP
Y1: 25MHz; Crystal_SMD_2016-4Pin_2.0x1.6mm; Mfr. Part # XRCGB25M000F3L25R0
Y2: 32.768KHz; Crystal_SMD_2012-2Pin_2.0x1.2mm; Mfr. Part # FC2012SN

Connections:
+3V3: C2.1, C3.1, C4.1, C5.1, C37.1, C38.1, FB1.1, J1.1, JP2.1 (A), JP3.3 (B), R14.1, R15.1, U1.24 (VDD), U1.36 (VDD), U1.48 (VDD), U8.1 (~RESET), U8.14 (V_{DD(P)}), U8.15 (V_{DD(I2C)}); also elsewhere on the board
/Audio/DAC_BCK: U1.18 (PB0); also elsewhere on the board
/Audio/DAC_DIN: U1.31 (PA10); also elsewhere on the board
/Audio/DAC_LRCK: U1.19 (PB1); also elsewhere on the board
/Audio/DAC_XSMT: U1.20 (PB2); also elsewhere on the board
/Audio/MIC_SCK: U1.25 (PB12); also elsewhere on the board
/Audio/MIC_SD: U1.41 (PB5); also elsewhere on the board
/Audio/MIC_WS: U1.38 (PA15); also elsewhere on the board
/Buttons/Down: U8.3 (P1); also elsewhere on the board
/Buttons/Left: U8.4 (P2); also elsewhere on the board
/Buttons/Ok: U8.7 (P4); also elsewhere on the board
/Buttons/Right: U8.5 (P3); also elsewhere on the board
/Buttons/Up: U8.2 (P0); also elsewhere on the board
/Buttons/V+: U8.8 (P5); also elsewhere on the board
/Buttons/V-: U8.9 (P6); also elsewhere on the board
/Display/BL: U1.45 (PB8); also elsewhere on the board
/Display/CLK: U1.26 (PB13); also elsewhere on the board
/Display/CS: U1.13 (PA3); also elsewhere on the board
/Display/DC: U1.10 (PA0); also elsewhere on the board
/Display/DIN: U1.11 (PA1); also elsewhere on the board
/Display/RST: U1.12 (PA2); also elsewhere on the board
/MCU/+3V3A: C6.1, C7.1, FB1.2, U1.9 (VDDA)
/MCU/+VBAT: C1.1, U1.1 (VBAT); also elsewhere on the board
/MCU/ADDR_SELECT: JP3.2 (C), U8.16 (ADDR)
/MCU/BOOT0: R1.2, U1.44 (BOOT0)
/MCU/BOOT0R: JP2.2 (C), R1.1
/MCU/HSE_IN: C10.1, U1.5 (PH0), Y1.1
/MCU/HSE_OUT: C9.1, TP7.1 (1_1), U1.6 (PH1), Y1.3
/MCU/LSE_IN: C11.1, U1.3 (PC14), Y2.1
/MCU/LSE_OUT: C12.1, TP8.1 (1_1), U1.4 (PC15), Y2.2
/MCU/MUX_INT: U1.2 (PC13), U8.11 (~INT)
/MCU/NRST: J1.3, U1.7 (NRST)
/MCU/SCL: R14.2, TP9.1 (1_1), U1.42 (PB6), U8.12 (SCL); also elsewhere on the board
/MCU/SDA: R15.2, TP10.1 (1_1), U1.46 (PB9), U8.13 (SDA); also elsewhere on the board
/MCU/SD_CLK: U1.28 (PB15); also elsewhere on the board
/MCU/SD_CMD: U1.16 (PA6); also elsewhere on the board
/MCU/SD_DAT0: U1.43 (PB7); also elsewhere on the board
/MCU/SWCLK: J1.4, U1.37 (PA14)
/MCU/SWDIO: J1.2, U1.34 (PA13)
/MCU/SWO: J1.6, U1.39 (PB3)
/MCU/U_D+: U1.33 (PA12); also elsewhere on the board
/MCU/U_D-: U1.32 (PA11); also elsewhere on the board
/MCU/U_Output SW: U8.10 (P7); also elsewhere on the board
/MCU/U_Sensing_USB-A: U1.30 (PA9); also elsewhere on the board
/MCU/U_Sensing_USB-C: U1.29 (PA8); also elsewhere on the board
/MCU/VCAP: C8.1, U1.22 (VCAP1)
/MCU/W_CLK: U1.15 (PA5); also elsewhere on the board
/MCU/W_CS: U1.14 (PA4); also elsewhere on the board
/MCU/W_Chip_EN: U1.21 (PB10); also elsewhere on the board
/MCU/W_MISO: U1.40 (PB4); also elsewhere on the board
/MCU/W_MOSI: U1.17 (PA7); also elsewhere on the board
/MCU/W_RDY: U1.27 (PB14); also elsewhere on the board
GND: C1.2, C2.2, C3.2, C4.2, C5.2, C6.2, C7.2, C8.2, C9.2, C10.2, C11.2, C12.2, C37.2, C38.2, J1.5, JP2.3 (B), JP3.1 (A), U1.8 (VSSA), U1.23 (VSS), U1.35 (VSS), U1.47 (VSS), U1.49 (VSS), U8.6 (V_{SS}), U8.17 (V_{SS}), Y1.2 (G), Y1.4 (G); also elsewhere on the board

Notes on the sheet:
Enable pull-ups for buttons in frimware
Main MCU
Cut and bridge once MCU firmware is done
Change if it has address conflicts
Boot Set Pins
I2C MUX
C = 2 * (CL - Cstray) C = 2 * (6pf - 5pf) C = 2pf ~= 2.2pf
TagConnect Pins
I2C Test Points

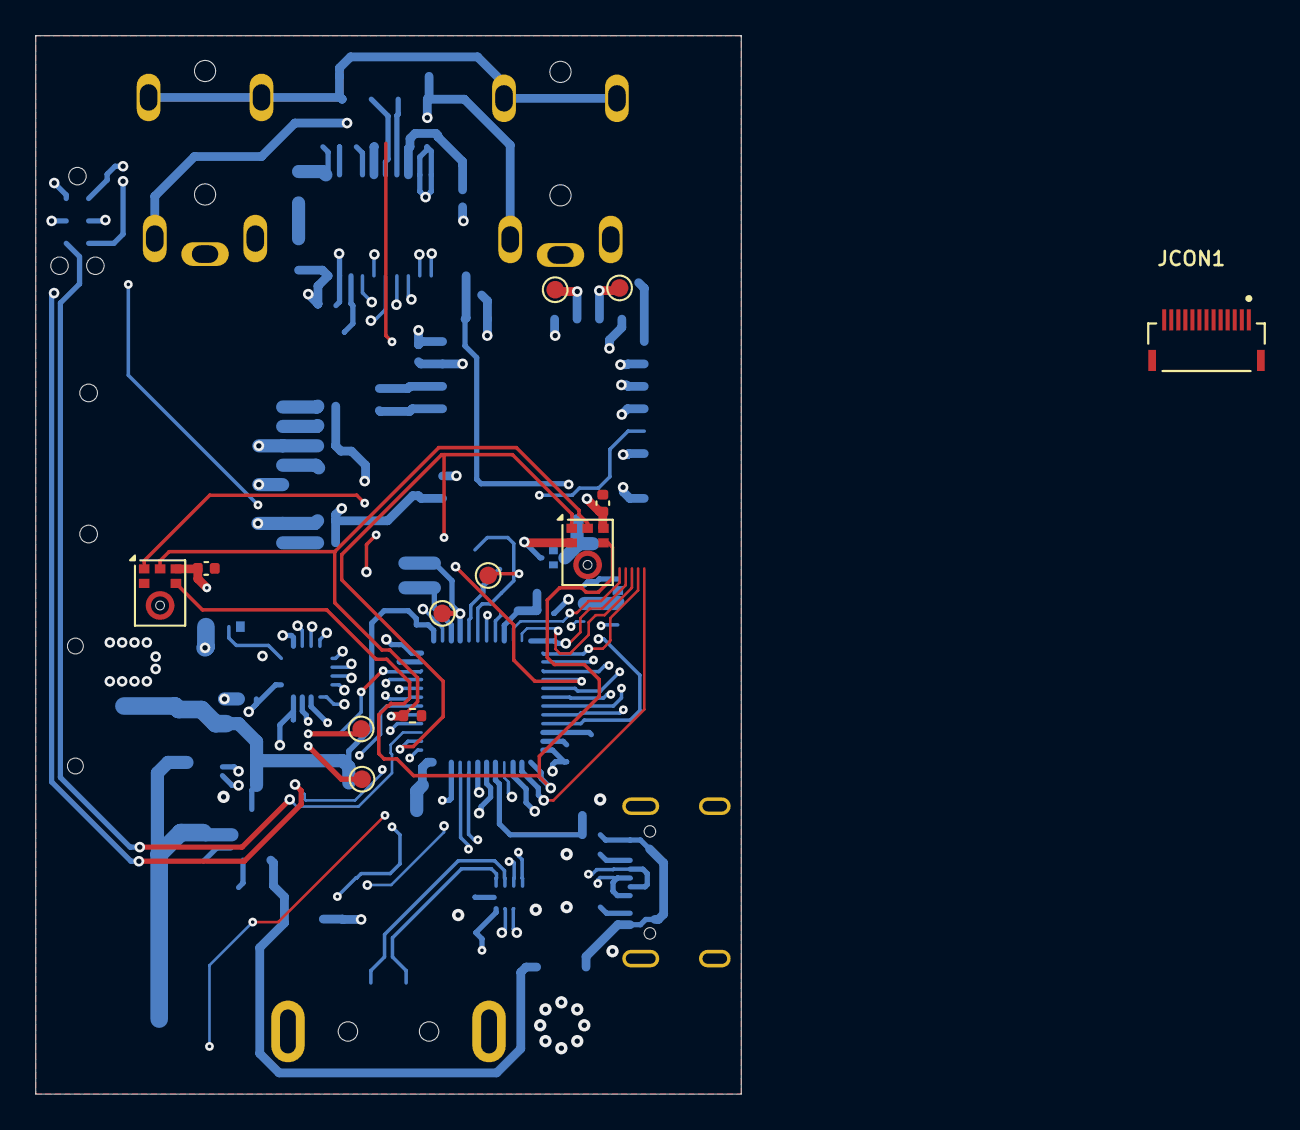
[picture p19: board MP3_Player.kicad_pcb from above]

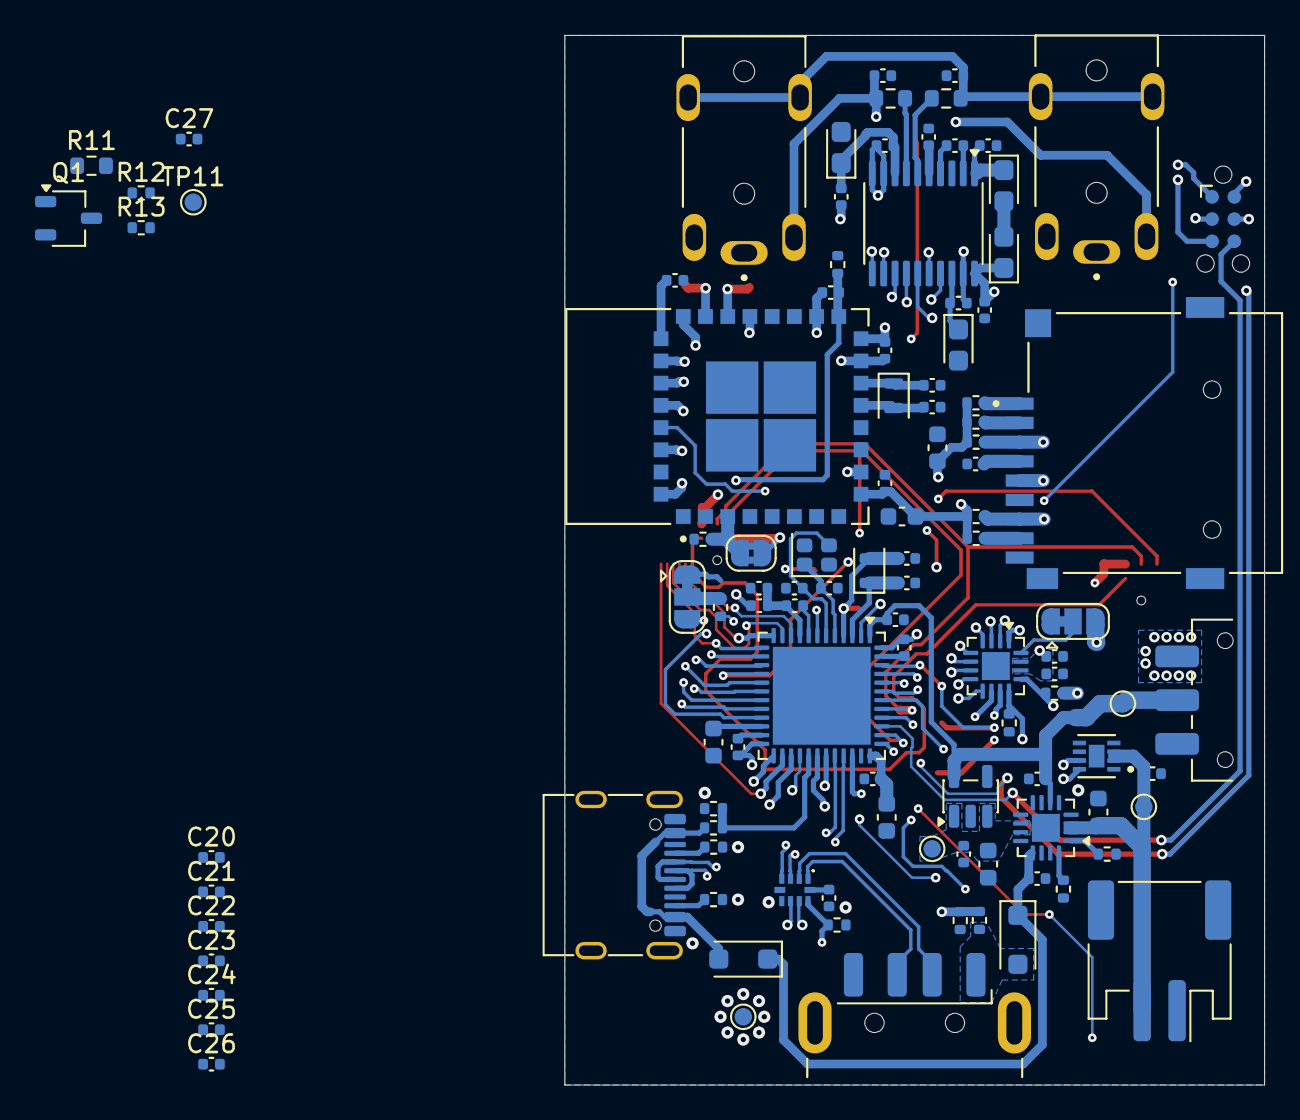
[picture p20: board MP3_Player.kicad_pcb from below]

Board: 6 copper layers, 40.0 x 60.0 mm, 118 parts (106 on the bottom side), 86 nets.

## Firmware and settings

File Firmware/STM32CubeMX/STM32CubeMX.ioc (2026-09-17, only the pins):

Mcu.UserName=STM32F411CEUx
PA0-WKUP.GPIO_Label=D_DC
PA0-WKUP.Signal=GPIO_Output
PA1.Signal=SPI4_MOSI
PA10.Signal=I2S5_SD
PA11.Signal=USB_OTG_FS_DM
PA12.Signal=USB_OTG_FS_DP
PA13.Signal=SYS_JTMS-SWDIO
PA14.Signal=SYS_JTCK-SWCLK
PA15.Signal=I2S3_WS
PA2.GPIO_Label=D_RST
PA2.Signal=GPIO_Output
PA3.GPIO_Label=D_CS
PA3.Signal=GPIO_Output
PA4.Signal=SPI1_NSS
PA5.Signal=SPI1_SCK
PA6.Signal=SDIO_CMD
PA7.Signal=SPI1_MOSI
PA8.GPIO_Label=Sens_USBC
PA8.Signal=GPIO_Input
PA9.GPIO_Label=Sens_USBA
PA9.Signal=USB_OTG_FS_VBUS
PB0.Signal=I2S5_CK
PB1.Signal=I2S5_WS
PB10.GPIO_Label=W_ChipEN
PB10.Signal=GPIO_Output
PB12.Signal=I2S3_CK
PB13.Signal=SPI4_SCK
PB14.GPIO_Label=W_RDY
PB14.Signal=GPIO_Input
PB15.Signal=SDIO_CK
PB2.GPIO_Label=CODEC_XSMT
PB2.Signal=GPIO_Output
PB3.Signal=SYS_JTDO-SWO
PB4.Signal=SPI1_MISO
PB5.Signal=I2S3_SD
PB6.Signal=I2C1_SCL
PB7.Signal=SDIO_D0
PB8.Signal=S_TIM10_CH1
PB9.Signal=I2C1_SDA
PC14-OSC32_IN.Signal=RCC_OSC32_IN
PC15-OSC32_OUT.Signal=RCC_OSC32_OUT

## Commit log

2026-09-20 Sync with desktop
    [MP3_Player.kicad_pcb, MP3_Player.kicad_sch, audio.kicad_sch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]
2026-09-20 Minor Schematic Changes
    [MP3_Player.kicad_sch, display.kicad_sch, mcu.kicad_sch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]
2026-09-21 Visual Schematic Corrections
    [mcu.kicad_sch, power.kicad_sch, usb.kicad_sch]
2026-09-21 Started Making BOM
    [audio.kicad_sch, buttons.kicad_sch, display.kicad_sch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]
2026-09-22 Continue Making BOM
    [audio.kicad_sch, buttons.kicad_sch, display.kicad_sch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]
2026-09-23 Finished BOM; Started Footprint assignment
    [audio.kicad_sch, buttons.kicad_sch, display.kicad_sch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]
2026-09-24 Footprint Assingment
    [audio.kicad_sch, display.kicad_sch, mcu.kicad_sch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]
2026-09-24 Footprint Assignment
    [buttons.kicad_sch, power.kicad_sch]
2026-09-25 Footprint Assingment Complete
    [audio.kicad_sch, display.kicad_sch, mcu.kicad_sch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]
2026-09-29 Starting PCB Layout
    [MP3_Player.kicad_pcb, audio.kicad_sch, mcu.kicad_sch]
2026-09-30 PCB Layout
    [MP3_Player.kicad_pcb, usb.kicad_sch, wireless.kicad_sch]
2026-10-06 PCB Routing
    [MP3_Player.kicad_pcb, usb.kicad_sch]
2026-10-27 Final PCB Routing
2026-10-29 PCB Correction
2026-11-03 Update BOM
2026-11-04 Gerbers plot
2026-11-06 BOM Corrections
